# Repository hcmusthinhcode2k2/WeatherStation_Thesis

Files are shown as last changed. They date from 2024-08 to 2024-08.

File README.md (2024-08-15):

## Thesis Topic: "Design a weather monitoring station using NB-IoT technology"

### Description
The weather station model was designed over a 5-month period (March 2024 - August 2024), incorporating components such as PCB, sensors, and mechanical structure. The objective of this project is to develop a station capable of collecting weather data from various sensors and transmitting it to the ThingsBoard server. This enables visualization of the collected data, facilitating effective weather monitoring.

The project benefited from equipment and guidance provided by RPC, the company where I interned from October 2023 to December 2023.

### Technology
- **Hardware**: Designed using the open-source software KiCad 8.0.
- **Firmware**: Developed for the PIC32MM0256GPM048 microcontroller, leveraging existing RPC libraries such as Telit, Bootloader, and VCP_debug. Tools used include MPLAB X IDE version 6.20 and Serial Port Terminal version 1.5.0.4.
- **Server**: ThingsBoard is utilized to create a website with widgets for visualizing weather data, GPS-based map locations, warning clocks, and more.

### Model Images and Implementation Results
#### Weather Station Board
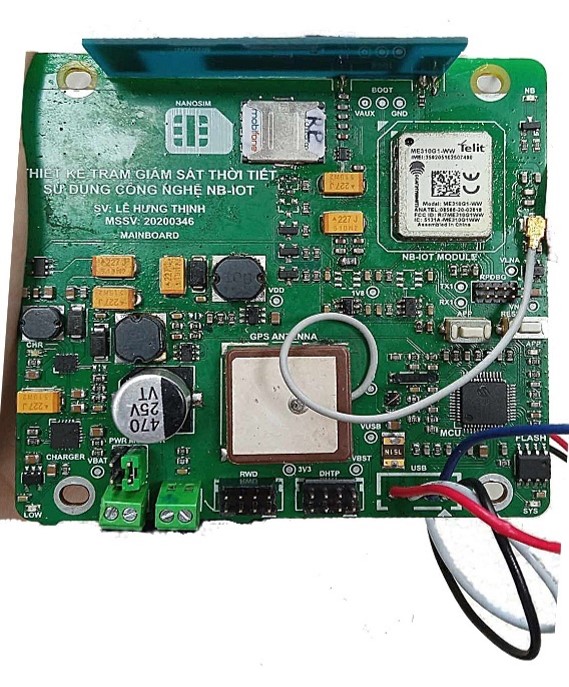
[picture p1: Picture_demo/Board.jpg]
Weather Station Board


#### Device Images
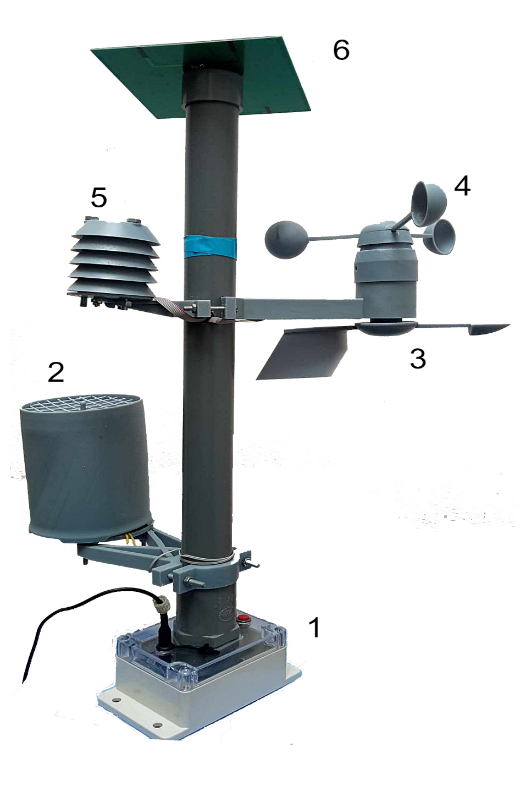
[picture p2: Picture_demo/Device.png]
Device Images


#### ThingsBoard Dashboard
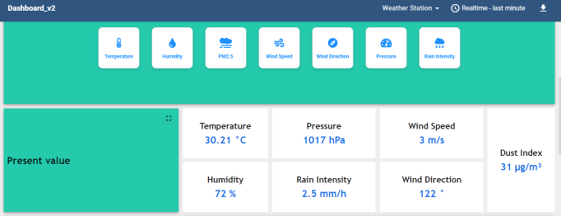
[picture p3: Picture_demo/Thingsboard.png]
ThingsBoard Dashboard

- [Access the ThingsBoard Dashboard](https://demo.thingsboard.io/dashboard/4821b720-32a0-11ef-9229-f3aa570680fb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)

### Developed After Defending The Thesis
Post-thesis, I built a web application using Next.js, integrating it with the ThingsBoard API for interactive weather data visualization. Supabase is used for backend services, including authentication via GitHub, data management, and real-time updates. The development process was influenced by insights from this [YouTube video](https://www.youtube.com/watch?v=zOgFMPC12Ag).
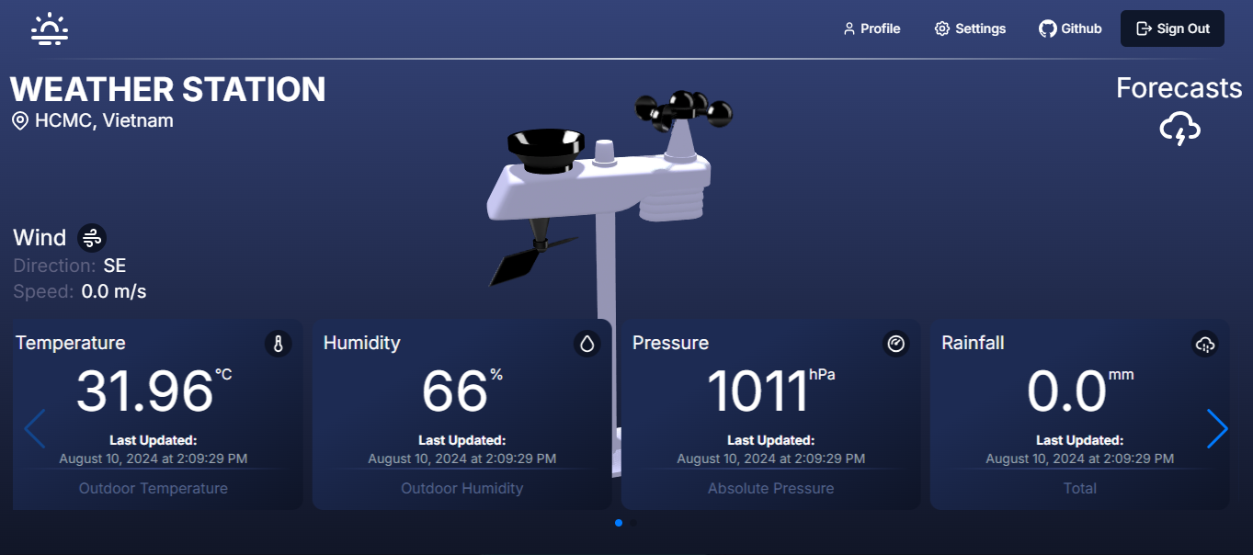
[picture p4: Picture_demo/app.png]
Web

- [Access the Web](https://iot-dashboard-2r98-git-master-hcmusthinhcode2k2s-projects.vercel.app/auth)
- **Test Credentials**: 
  - **Username**: test1@gmail.com
  - **Password**: Test123@
### Demo
[Demo1](https://www.youtube.com/watch?v=N3w6X92QKFQ)
[Demo2](https://youtu.be/iBSUhQx9wfY)

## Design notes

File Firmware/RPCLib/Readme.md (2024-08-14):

# RPC STATIC LIBRARY FOR MICROCHIP MCUs

Support MPALB XC Compilers

## 1. 8-Bit PIC MCUs

## 2. 8-Bit AVR MCUs

## 3. 16-Bit PIC MCUs

## 4. 32-Bit MIPS MCUs

## 5. 32-Bit ARM MCUs

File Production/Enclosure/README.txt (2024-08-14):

YAWS, Yet Another Weather Station by BennyI3 on Thingiverse: https://www.thingiverse.com/thing:6439737

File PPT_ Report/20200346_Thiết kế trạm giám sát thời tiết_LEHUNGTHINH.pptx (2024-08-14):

## KHOÁ LUẬN TỐT NGHIỆP CỬ NHÂN

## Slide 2

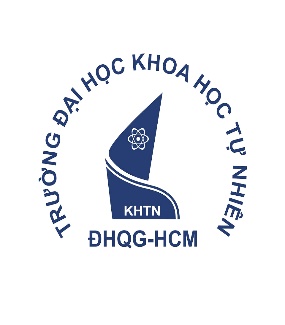
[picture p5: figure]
Không có mô tả ảnh.
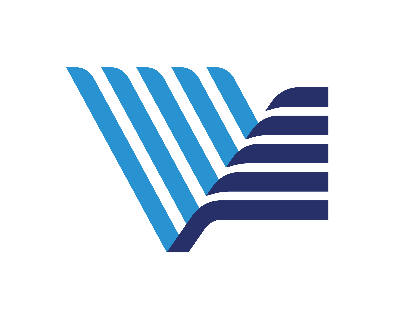
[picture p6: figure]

TRƯỜNG ĐẠI HỌC KHOA HỌC TỰ NHIÊN- ĐHQG THÀNH PHỐ HỒ CHÍ MINH
KHOA ĐIỆN TỬ - VIỄN THÔNG
BỘ MÔN MÁY TÍNH - HỆ THỐNG NHÚNG

Thành phố Hồ Chí Minh, Ngày 3 tháng 8 năm 2024

Đề tài:

THIẾT KẾ TRẠM GIÁM SÁT THỜI TIẾT
SỬ DỤNG CÔNG NGHỆ NB-IOT

Sinh viên : Lê Hưng Thịnh
MSSV : 20200346 – ĐTVT K20
GVHD : ThS. Nguyễn Quốc Khoa

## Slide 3

NỘI DUNG TRÌNH BÀY

1

TỔNG QUAN ĐỀ TÀI

2

THIẾT KẾ MÔ HÌNH

3

KIỂM THỬ – ĐÁNH GIÁ

KẾT LUẬN – HƯỚNG PHÁT TRIỂN

4

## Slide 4

1

TỔNG QUAN ĐỀ TÀI

1.1 Đặt vấn đề

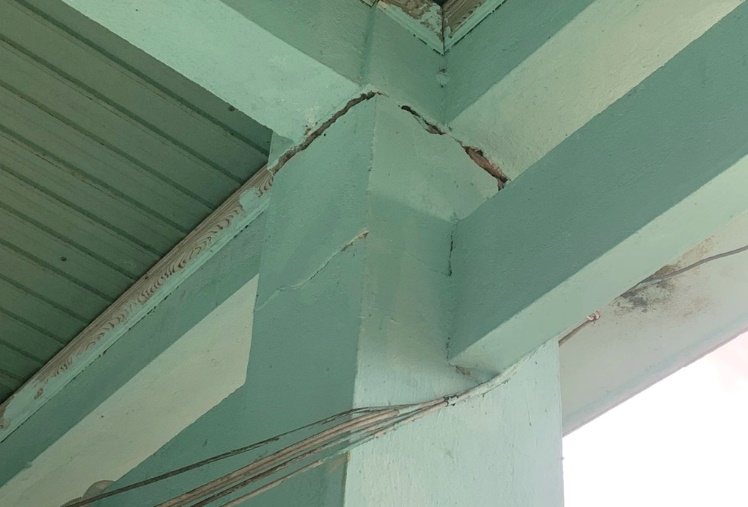
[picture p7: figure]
Động đất 5.0 độ ở Kon Tum: Nhiều công trình ở vùng tâm chấn bị nứt | Báo Dân trí

Động đất liên tiếp ở Kon Tum

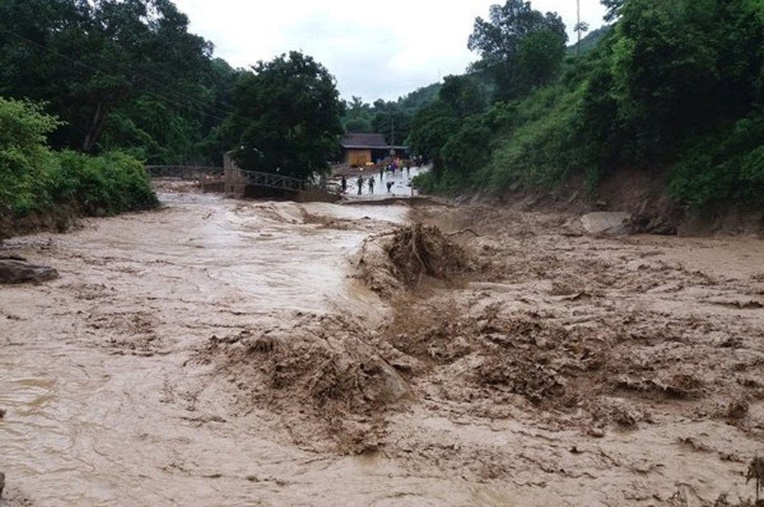
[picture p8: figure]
Vì sao miền Bắc xuất hiện nhiều điểm mưa lũ lịch sử trong tháng 7?

Lũ lớn ở miền bắc

Vấn đề : Giám sát dữ liệu thời tiết.
Trực quan hoá dữ liệu đưa ra cảnh báo kịp thời.

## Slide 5

1

TỔNG QUAN ĐỀ TÀI

Trạm giám sát thời tiết Wireless Vantage Pro2

1.1 Đặt vấn đề

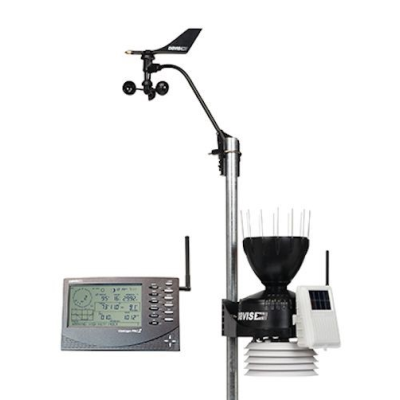
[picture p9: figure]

Ưu: Độ chính xác cao, thiết kế bền bỉ, khả năng mở rộng.
Nhược: Chi phí cao, truyền dữ liệu phạm vi ngắn, tiêu thụ năng lượng cao.

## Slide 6

1

TỔNG QUAN ĐỀ TÀI

1.2 Mục tiêu của khoá luận tốt nghiệp

Thiết kế một mô hình trạm giám sát thời tiết sử dụng công nghệ NarrowBand – Internet of Things (NB-IoT) có khả năng thu thập và gửi dữ liệu thời tiết lên server nhanh chóng:
- Dữ liệu từ cảm biến.
- Kết nối server bằng cách sử dụng mạng NB-IoT.
Giai đoạn của đề tài: giai đoạn sơ khai (tính toán thiết kế board mạch trên phần mềm Kicad, hàn lắp gia công, thiết kế chương trình, lắp đặt mô hình).

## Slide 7

2

THIẾT KẾ MÔ HÌNH

2.1 Yêu cầu chung của mô hình

- Thiết kế board mạch có đầy đủ các thành phần như nguồn, vi điều khiển, module truyền thông, …
- Có khả năng thu thập dữ liệu thời tiết với mức độ chính xác tương đối.
- Thực hiện kết nối server bằng mạng NarrowBand – Internet of Things (NB-IoT).
- Trực quan hoá và cảnh báo dựa trên dữ liệu thời tiết nhận được trên server server thông qua Thingsboard,.
- Lắp rắp thiết kế được mô hình hoàn chỉnh.

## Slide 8

2

THIẾT KẾ MÔ HÌNH

2.1 Tổng quan mô hình

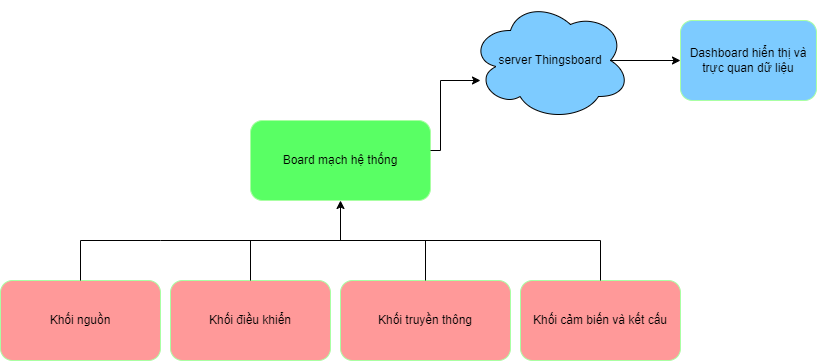
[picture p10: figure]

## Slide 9

2

THIẾT KẾ MÔ HÌNH

2.2 Phân hệ thiết kế phần cứng

Khối nguồn

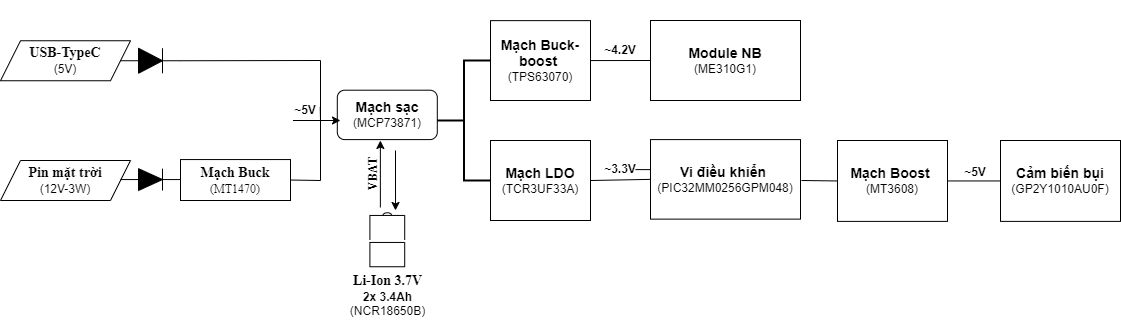
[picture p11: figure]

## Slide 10

2

THIẾT KẾ MÔ HÌNH

2.2 Phân hệ thiết kế phần cứng

Khối điều khiển

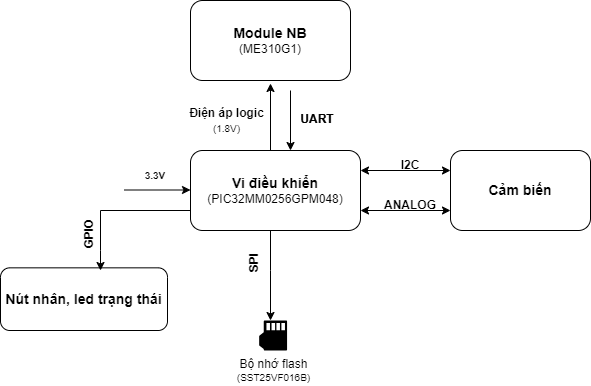
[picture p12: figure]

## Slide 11

2

THIẾT KẾ MÔ HÌNH

2.2 Phân hệ thiết kế phần cứng

Khối truyền thông

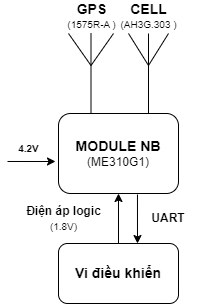
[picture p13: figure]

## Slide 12

2

THIẾT KẾ MÔ HÌNH

2.2 Phân hệ thiết kế phần cứng

Khối cảm biến và kết cấu

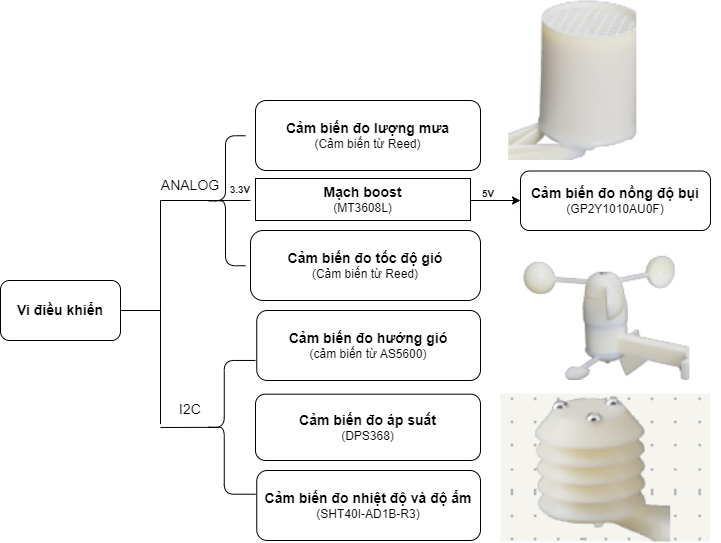
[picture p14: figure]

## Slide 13

2

THIẾT KẾ MÔ HÌNH

2.3 Phân hệ thiết kế chương trình

Cấu trúc chương trình điều khiển

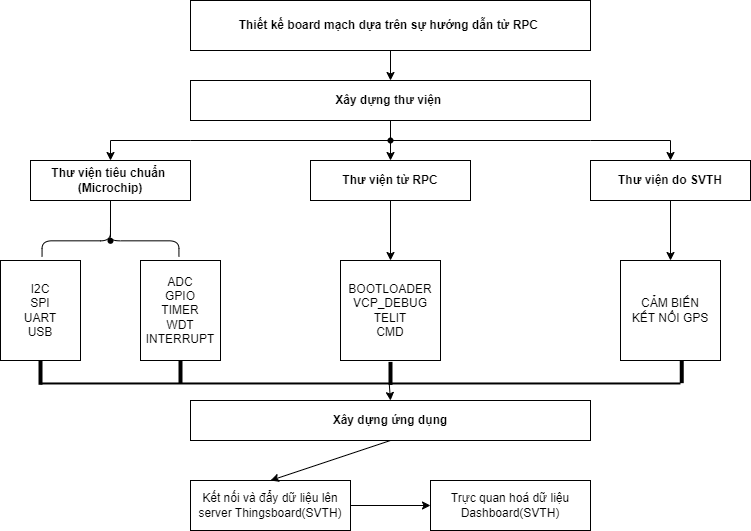
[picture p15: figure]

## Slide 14

2

THIẾT KẾ MÔ HÌNH

2.3 Phân hệ thiết kế chương trình

Lưu đồ Module NB hoạt động.

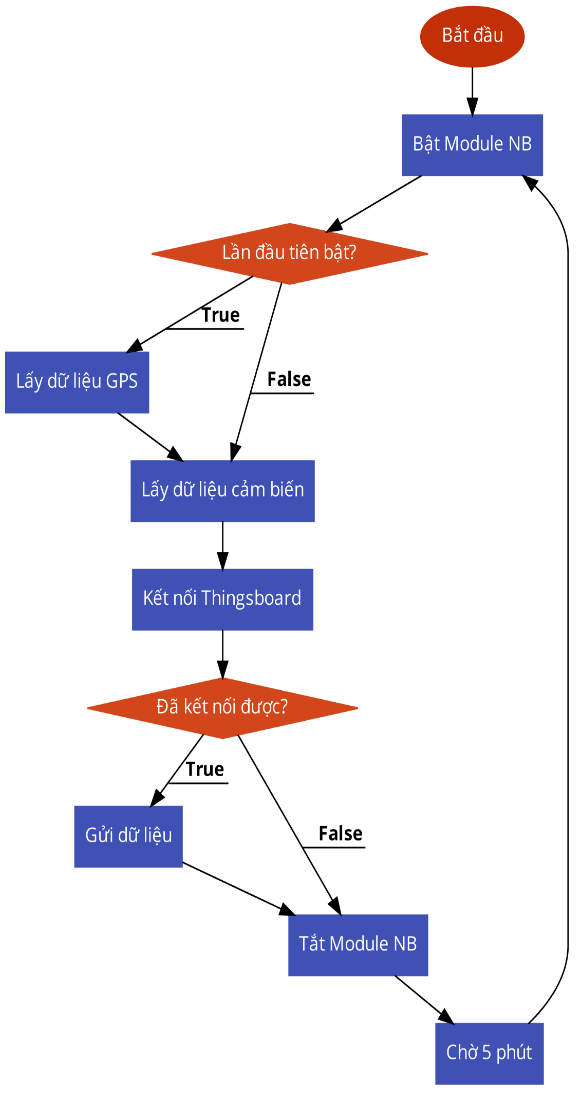
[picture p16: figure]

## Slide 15

2

THIẾT KẾ MÔ HÌNH

2.3 Phân hệ thiết kế chương trình

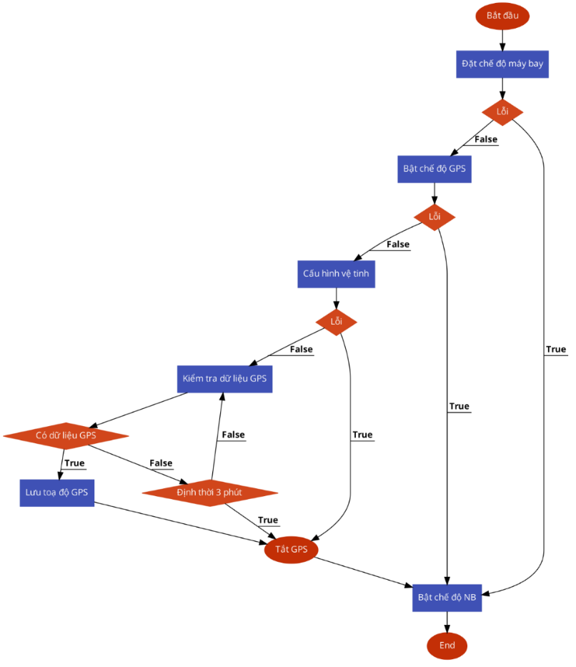
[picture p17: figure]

Lưu đồ thuật toán lấy dữ liệu GPS.

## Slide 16

2

THIẾT KẾ MÔ HÌNH

2.4 Phân hệ thiết kế chương trình

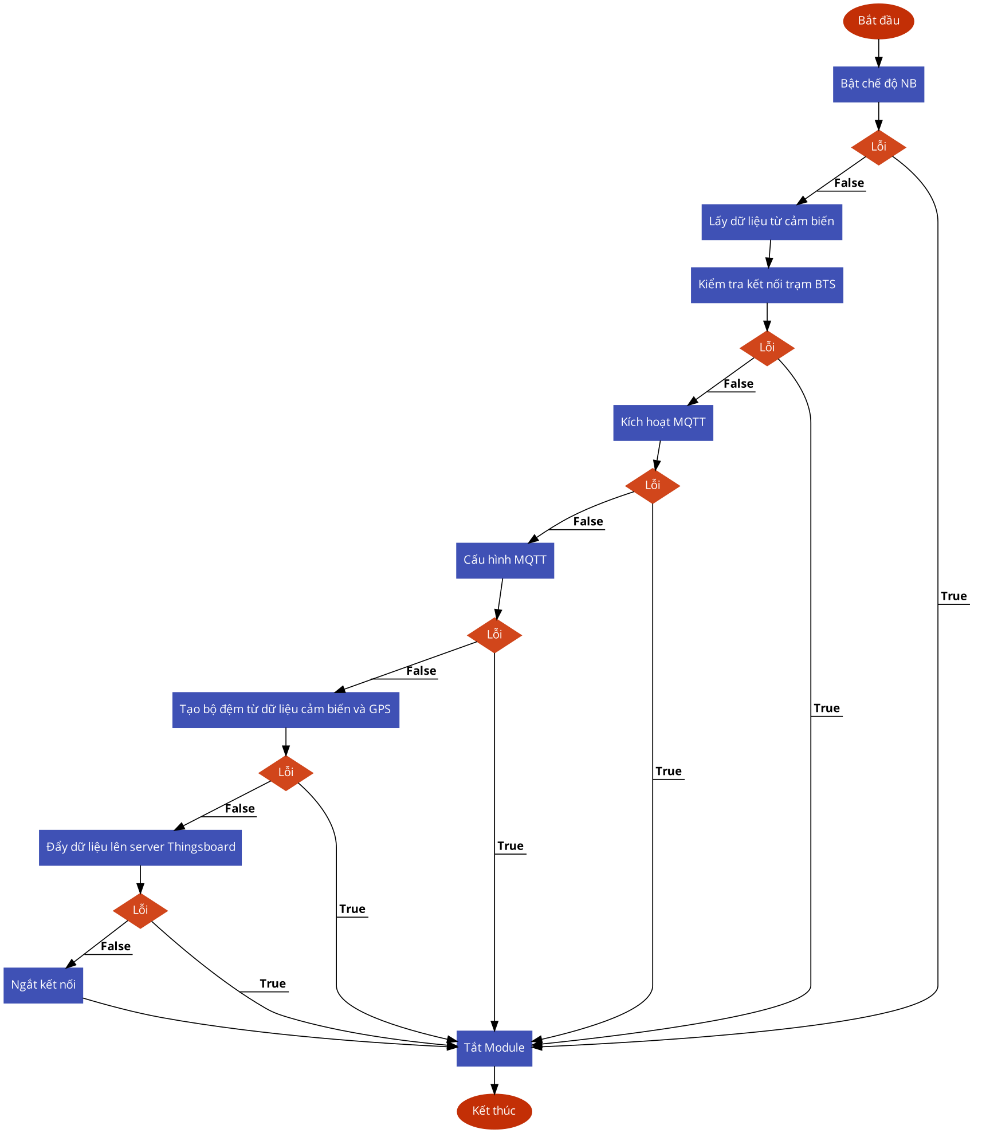
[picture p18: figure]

Lưu đồ thuật toán lấy dữ liệu và gửi
dữ liệu lên server.

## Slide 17

2

THIẾT KẾ MÔ HÌNH

2.4 Phân hệ thiết kế Dashboard trên Thingsboard

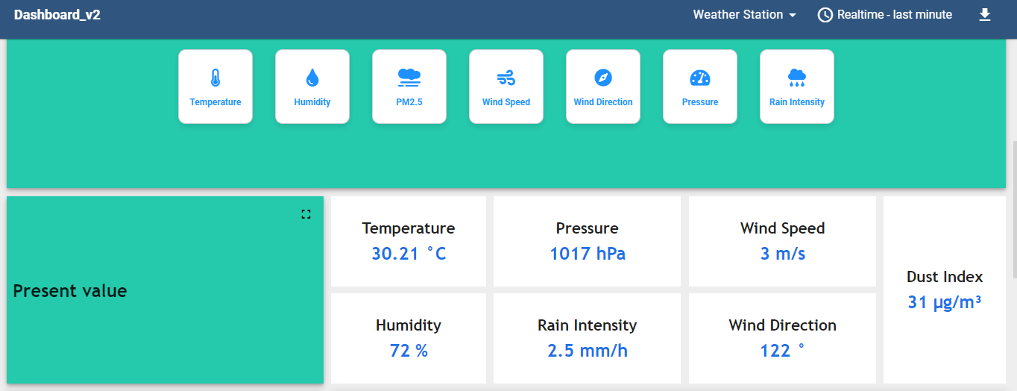
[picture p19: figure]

Thiết kế trang tổng quan

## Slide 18

2

THIẾT KẾ MÔ HÌNH

2.4 Phân hệ thiết kế Dashboard trên Thingsboard

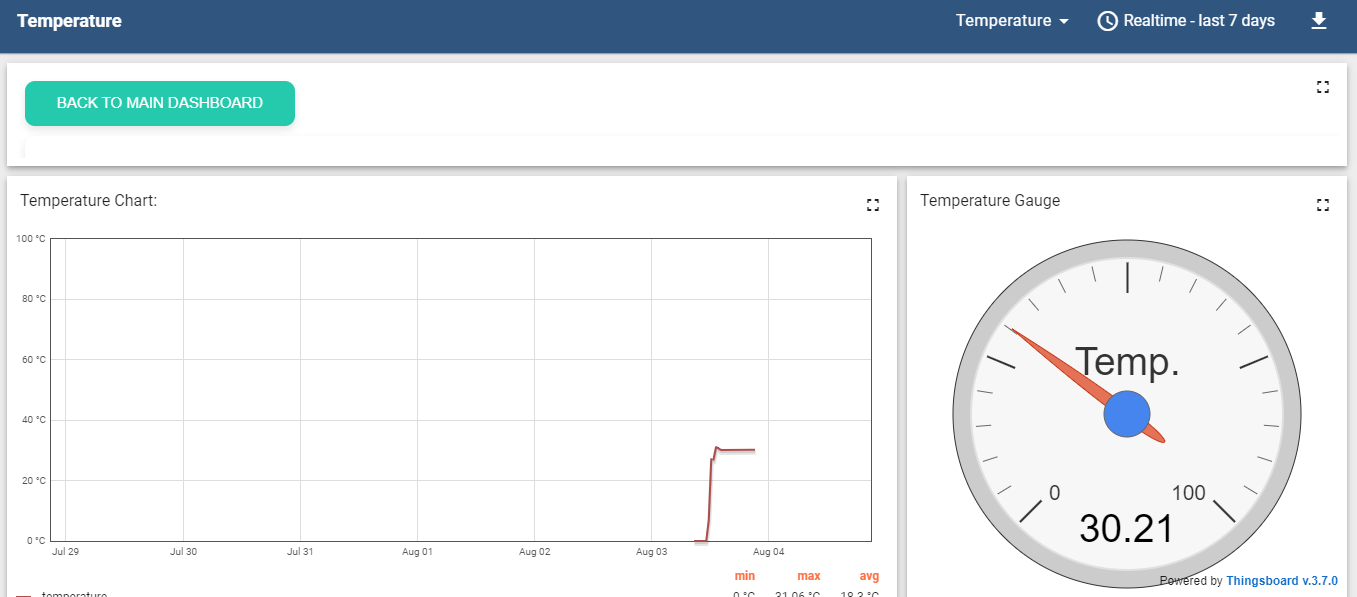
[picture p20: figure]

Thiết kế trang con

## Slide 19

3

KIỂM THỬ - ĐÁNH GIÁ

3.1 Điều kiện kiểm thử (ĐKKT)

Thời gian: Sau khi hàn lắp gia công board mạch.
Hệ thống : Nguồn tại các vị trí như chân vi điều khiển, chân module NB, chân nguồn vào pin Li-Ion, pin mặt trời, nguồn tại các chân IC Buck, boost.
Phương tiện: Đồng hồ VOM.

Board mạch hệ thống

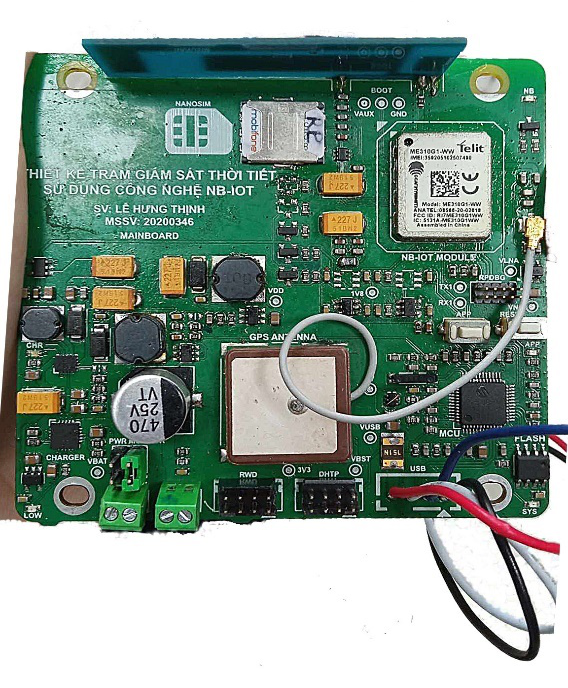
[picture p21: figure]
Bản xem trước hình ảnh

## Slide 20

3

KIỂM THỬ - ĐÁNH GIÁ

3.2 Kiểm tra mô hình hoạt động

Thời gian: Sau khi lắp ráp mô hình hoàn chỉnh.
Hệ thống : Chương trình điều khiển hoạt động thu thập dữ liệu của cảm biến, kết nối GPS và truyền dữ liệu lên server.
Phương tiện:Bootloader, VCP_DEBUG.

Mô hình đã lắp đặt hoàn chỉnh


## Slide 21

3

KIỂM THỬ - ĐÁNH GIÁ

3.2 Kiểm tra dữ liệu trên server

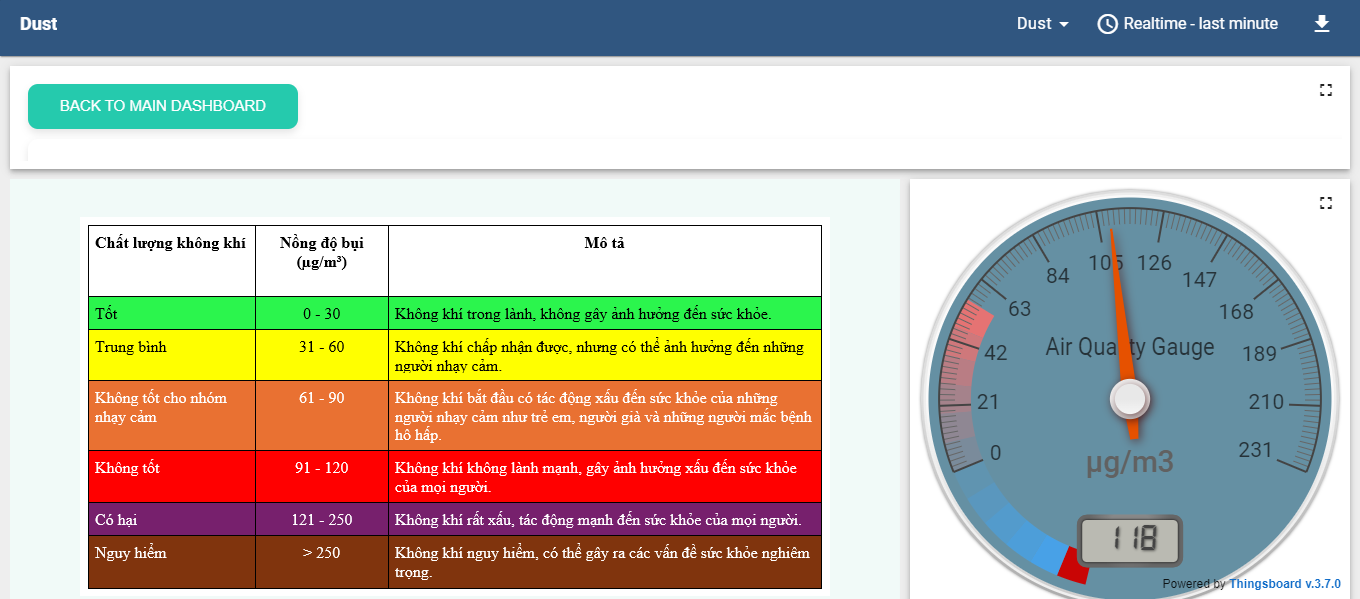
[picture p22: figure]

Thời gian: Sau khi chương trình kích hoạt
Hệ thống : Đã kết nối đến server
Phương tiện: Thingsboard (bản demo).

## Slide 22

3

KIỂM THỬ - ĐÁNH GIÁ

3.3 Đánh giá

Kết quả thực nghiệm:
Đối với board mạch:
- Nguồn tương đối chính xác cho vi điều khiển (~3.25V), Pin Li-Ion (~4.1V), module NB (~3.67V), cảm biến bụi (~5.1V). Pin năng lượng mặt trời (~11.5V).
Đối với mô hình hoàn chỉnh:
- Thu thập được các giá trị thời tiết từ cảm biến, GPS tương đối chính xác.
- Kết nối và truyền dữ liệu lên server tại một số địa điểm như CS1 ĐHKHTN, phường 12 quận Tân Bình, ktx khu B - ĐHQGHCM.
- Tiêu thụ năng lượng thấp theo tính toán khoảng 7 ngày.

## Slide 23

4

KẾT LUẬN – HƯỚNG PHÁT TRIỂN

4.1 Kết luận

Đạt được

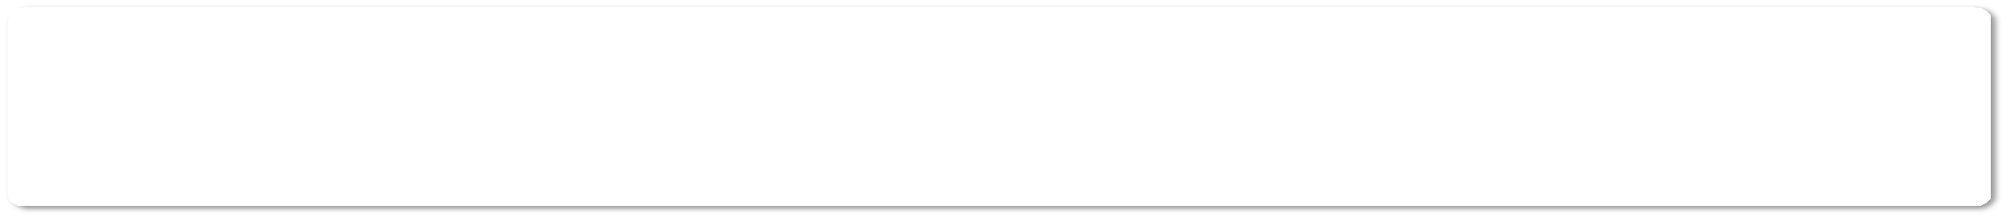
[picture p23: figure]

Khoá luận đã thiết kế thành công một mô hình IoT.
- Mô hình thực hiện đươc những tính năng đề ra.
- Mô hình có kết cấu và đi dây gọn gàn, dễ di chuyển.

- Trạm dừng lại ở mô hình với kết cấu được in3D nhựa resin.
- Độ chính xác cảm biến chưa tốt vì mẫu in 3D bị mốp méo, GPS sai lệch 5-20 m.
- Giao diện Dashboard trên Thingsboard chưa thiết kế tối ưu cho người dùng điện thoại xem.
- Chưa thực nghiệm được ở nhiều ĐKKT khác nhau.

Hạn chế

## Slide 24

4

KẾT LUẬN – HƯỚNG PHÁT TRIỂN

4.2 Hướng phát triển

- Tối ưu năng lượng tăng tuổi thọ của pin Li-Ion.
- Xây dựng thêm nhiều trạm có kết cấu vững chắc hơn. Từ đó có nhiều dữ liệu thời tiết, xây dựng mô hình dư báo thời tiết.
- Kiểm tra đánh giá chất lượng mạng NB-IoT tại nhiều nơi trước khi lắp đặt thử nghiệm trạm.
- Xây dựng thêm các nền tảng app/web với server cá nhân từ đó cải thiện khả năng bảo mật cũng như thiết kế giao diện người dùng thân thiệt trên IOS, Android.

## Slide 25

CẢM ƠN SỰ THEO DÕI CỦA QUÝ THẦY CÔ.

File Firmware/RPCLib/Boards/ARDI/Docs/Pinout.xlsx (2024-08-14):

Pin | Port | Name | Type | Init State | Note
21 | RA0 | UNO_VREF | Analog Input | x
22 | RA1 | UNO_AN3 | Analog Input | x
13 | RA10 | BUTTON | Digital Input | x
8 | RA15 | LED2 | Digital Output | 0
32 | RA2 | OSC1 | XTAL | x | XTAL 12MHz
33 | RA3 | OSC2 | XTAL | x | XTAL 12MHz
36 | RA4 | UNO_TXD | UART 3 TX | 1
20 | RA6 | LIGHT_INT | Digital Input | x
14 | RA7 | LED1 | Digital Output | 0
34 | RA8 | ACC_INT1 | Digital Input | x
37 | RA9 | UNO_MISO | SPI2 SDI | x
23 | RB0 | ICSP_PGD | Digital Input | x
24 | RB1 | ICSP_PGC | Digital Input | x
9 | RB10 | USB_N | USB D- | x
10 | RB11 | USB_P | USB D+ | x
12 | RB13 | VBAT_DIV | Analog Input | x | Rt/Rb=825k/825k
15 | RB14 | CELL_RING | Digital Input, Pullup | x | Active low, connect to Cellular pin C125/RING
16 | RB15 | TEM_INT | Digital Input | x
25 | RB2 | UNO_SDA | I2C2 SDA | x
26 | RB3 | UNO_SCL | I2C2 SCL | x
35 | RB4 | UNO_RXD | UART 3 RX | x
45 | RB5 | UNO_MOSI | SPI2 SDO | x
46 | RB6 | USB_VBUS | USB VBUS | x
47 | RB7 | UNO_SCLK | SPI2 SCK | x
48 | RB8 | SENSOR_SCL | I2C1 SCL | x
1 | RB9 | SENSOR_SDA | I2C1 SDA | x
27 | RC0 | UNO_AN1 | Analog Input | x
28 | RC1 | UNO_AN2 | Analog Input | x
44 | RC12 | CELL_PWR_EN | Digital Output | 0 | On/Off power of Cellular module
29 | RC2 | ACC_INT2 | Digital Input | x
39 | RC3 | UNO_INT1 | Digital Input | x
40 | RC4 | UNO_IO3 | Digital Input | x
41 | RC5 | UNO_INT0 | Digital Input | x
2 | RC6 | CELL_RXD | UART 2 RX | x | Connect to Cellular pin C104/RXD
3 | RC7 | CELL_TXD | UART 2 TX | 1 | Connect to Cellular pin C103/TXD
4 | RC8 | CELL_HWSDN | Digital Output | 0 | Active high, connect to Cellular HW_SHUTDOWN
5 | RC9 | CELL_WDT | Digital Input, Pullup | x | Active low, connect to Cellular GPIO_10
38 | RD0 | FLASH_CS_N | Digital Output | 1

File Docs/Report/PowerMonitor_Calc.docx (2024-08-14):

V_(REF) =3300 mV ADC_(RES) =4096

R_t =53.6K

R_b =10.0K

ADC_(RES) =4096

V_(SEN) =ADC_(VAL) ×(V_(REF))/(ADC_(RES))

V_o =(V_(SEN))/(R_b)×(R_t +R_b )=ADC_(VAL) ×(V_(REF))/(ADC_(RES))×(R_t +R_b)/(R_b)=ADC_(VAL) ×3300/4096×(R_t +R_b)/(R_b)

R_t =R_11 =53.6K;R_b =R_12 =10.0K

V_(5V) =ADC_(VAL) ×3300/4096×(53.6K+10.0K)/(10.0K)=ADC_(VAL) ×5247/1024

R_t =R_8 =43.0K;R_b =R_9 =12.0K

V_(NB) =ADC_(VAL) ×3300/4096×(43.0K+12.0K)/(12.0K)=ADC_(VAL) ×15125/4096

R_t =R_2 =5.1K;R_b =R_3 =10.0K

V_(SOLAR) =ADC_(VAL) ×3300/4096×(5.1K+10.0K)/(10.0K)=ADC_(VAL) ×4983/4096

R_t =R_19 =680.0K;R_b =R_20 =10.0K

V_(BAT) =ADC_(VAL) ×3300/4096×(680.0K+10.0K)/(10.0K)=ADC_(VAL) ×56925/1024

V_(NBAUX) =ADC_(VAL) ×3300/4096=ADC_(VAL) ×825/1024

V_(BG) =ADC_(VAL) ×3300/4096=ADC_(VAL) ×825/1024

V_(CORE) =ADC_(VAL) ×3300/4096=ADC_(VAL) ×825/1024

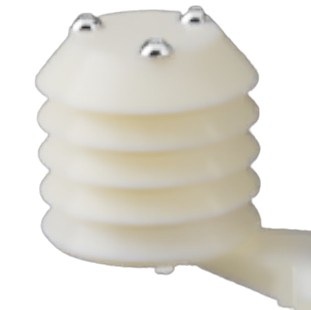
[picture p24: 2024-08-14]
Docs/Images/HumiditySensor.png

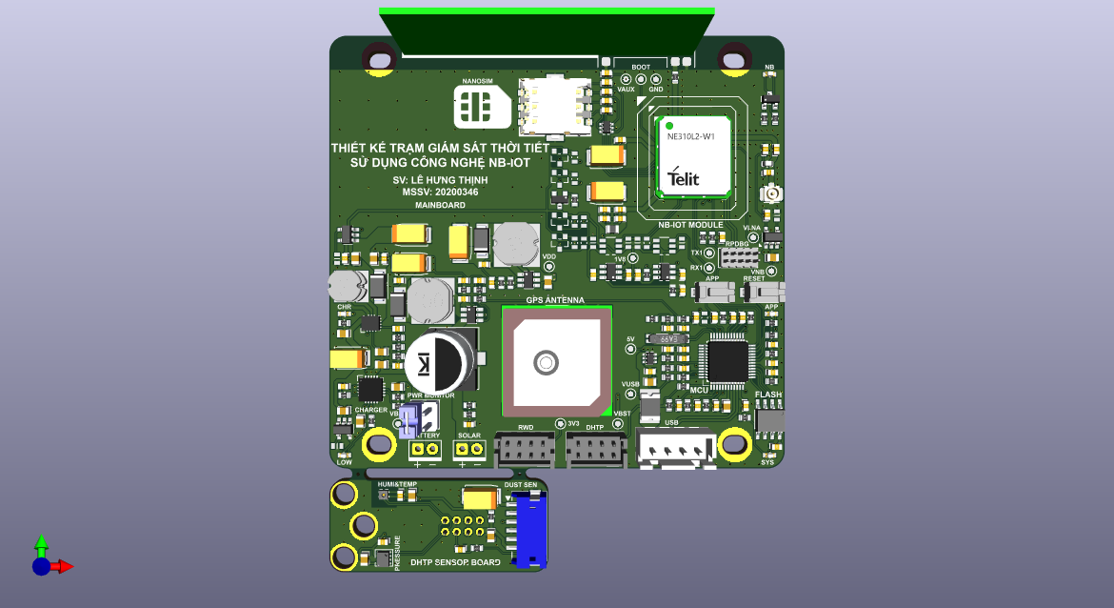
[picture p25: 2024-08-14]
Production/Main-Sen/Pictures/Top.png

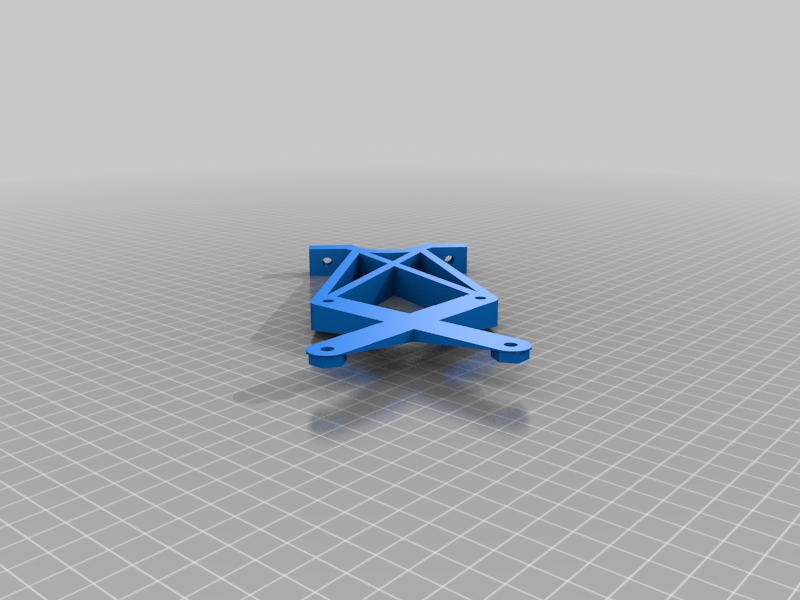
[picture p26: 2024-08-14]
Docs/Images/a5ba8f14-daac-4e57-8c12-72183b6821ad.png

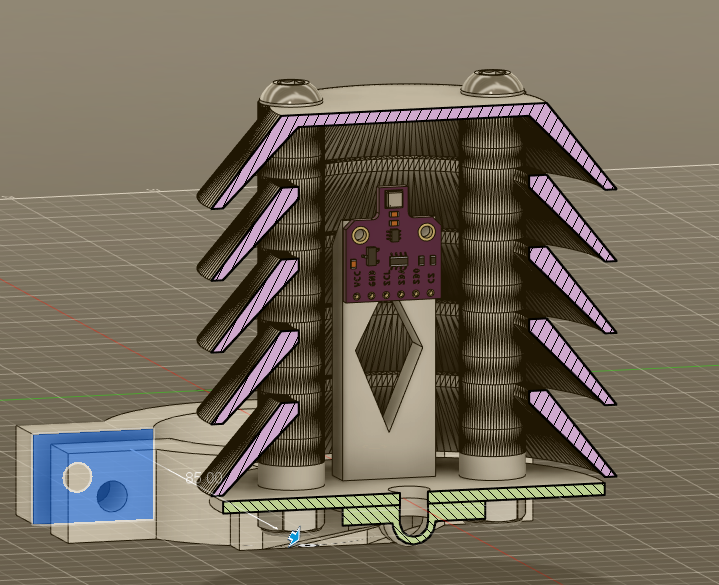
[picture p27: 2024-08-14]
Docs/Images/4b5391d4-0b75-4b54-ad87-2e042f95fe6b.png

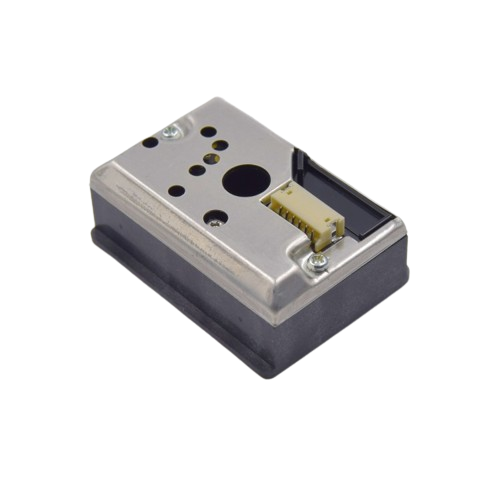
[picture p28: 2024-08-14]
Docs/Images/1-750x750-removebg-preview.png

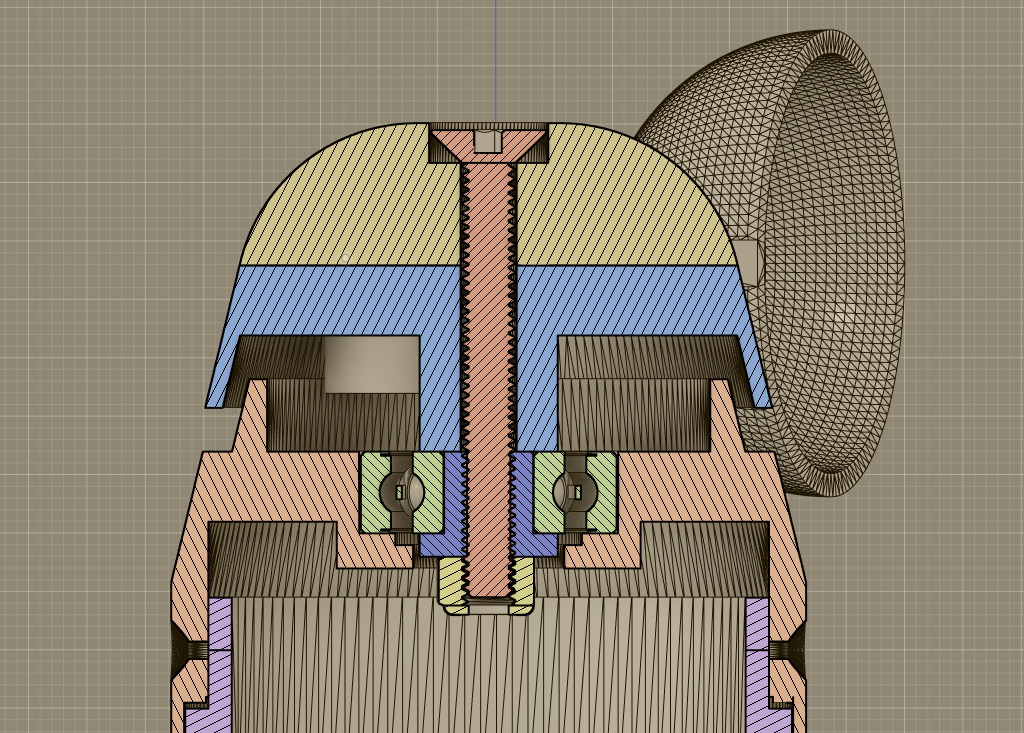
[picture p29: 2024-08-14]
Docs/Images/2bd4bd71-de33-4c61-b7e4-2078deda2e9a.png

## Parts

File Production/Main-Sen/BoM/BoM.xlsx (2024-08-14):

# | MNP | MFT | Description | Reference | Qty | Price | Sub-Price | Stock Link | Note
14 | VEC2R7106QC | VinaTech | SUPERCAP EDLC 10F 2.7V ESR 55mR | C57,C58 | 2 | 1.1285 | 2.2570 | https://banlinhkien.com/sieu-tu-10f-2.7v-10x30mm-vec2r7106qc-p12117721.html
38 | AS5600-I2C | OEM | 12-BIT MAGNETIC ROTARY | MD4 | 1 | 2.2000 | 2.2000 | https://icdayroi.com/module-cam-bien-goc-quay-bang-tu-truong-as5600-i2c
64 | DPS368XTSA1 | Infineon | SENSOR 17.4PSIG 24BIT 8VLGA | U14 | 1 | 3.1800 | 3.1800 | https://www.digikey.com/en/products/detail/infineon-technologies/DPS368XTSA1/10244079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
55 | MCP73871T-2CCI/ML | Microchip | IC BATT CHG LI-ION 1CELL 4.2V 20QFN | U4 | 1 | 2.4100 | 2.4100 | https://www.digikey.com/en/products/detail/microchip-technology/MCP73871T-2CCI-ML/1680976
~~58~~ | ~~PIC32MM0256GPM048-I/PT~~ | ~~Microchip~~ | ~~IC MCU 32BIT 256KB FLASH 48TQFP~~ | ~~U7~~ | ~~1~~ | ~~0~~ | ~~0~~ | https://www.digikey.com/en/products/detail/microchip-technology/PIC32MM0256GPM048-I-PT/7354721
~~57~~ | ~~SST25VF016B-50-4C-S2AF~~ | ~~Microchip~~ | ~~IC FLASH 16MBIT SPI 50MHZ 8SOIC~~ | ~~U6~~ | ~~1~~ | ~~0~~ | ~~0~~ | https://www.digikey.com/en/products/detail/microchip-technology/SST25VF016B-50-4C-S2AF/2297794
62 | SHT40I-AD1B-R3 | Sensirion | INDUSTRIAL SENSOR HUMID/TEMP | U12 | 1 | 2.1000 | 2.1000 | https://www.digikey.com/en/products/detail/sensirion-ag/SHT40I-AD1B-R3/15792545
~~51~~ | ~~MK20/2-B-100W~~ | ~~Standex~~ | ~~SENSOR REED SW SPST-NO CBL LEADS~~ | ~~SW1,SW2~~ | ~~2~~ | ~~0~~ | ~~0~~ | https://www.digikey.com/en/products/detail/standex-meder-electronics/MK20-2-B-100W/3131691
~~35~~ | ~~ME310G1WW05T060400~~ | ~~Telit~~ | ~~RF TXRX MODULE AT&T/VZW~~ | ~~MD1~~ | ~~1~~ | ~~0~~ | ~~0~~ | https://www.digikey.com/en/products/detail/telit-cinterion/ME310G1WW05T060400/20484831
54 | LM66100DCKR | TI | IC OR CTRLR IDEAL DIODE SC70-6 | U3 | 1 | 0.4100 | 0.4100 | https://www.digikey.com/en/products/detail/texas-instruments/LM66100DCKR/10273183
53 | TPS630701RNMR | TI | IC REG BCK BST 5V 2A 15VQFN | U2 | 1 | 1.8900 | 1.8900 | https://www.digikey.com/en/products/detail/texas-instruments/TPS630701RNMR/6175215
41 | RC0603FR-075K1L | YAGEO | RES SMD 5.1K OHM 1% 1/10W 0603 | R2,R5,R23,R24 | 4 | 0.0020 | 0.0080 | https://www.digikey.com/en/products/detail/yageo/RC0603FR-075K1L/727268
44 | RT0603FRE0736KL | YAGEO | RES SMD 36K OHM 1% 1/10W 0603 | R8 | 1 | 0.0020 | 0.0020 | https://www.digikey.com/en/products/detail/yageo/RT0603FRE0736KL/1075328
36 | 1575R-A | AntennaHome | GPS ACTIVE ANT 19X19 IPEX CONNECTOR RF CABLE 10CM | MD2 | 1 | 1.0530 | 1.0530 | https://www.thegioiic.com/1575r-a-ang-ten-active-gps-19x19-dau-ipex-cap-rf-10cm
~~1~~ | ~~AH3G.303~~ | ~~AntennaHome~~ | ~~ANTENNA SMD 2G/3G/4G 690~2700MHz~~ | ~~ANT1~~ | ~~1~~ | ~~0~~ | ~~0~~ | https://www.thegioiic.com/ah3g-303-ang-ten-smd-2g-3g-4g-690-2700mhz
25 | BK2125HS101-T | Taiyo Yuden | FERRITE BEAD 100 OHM 0805 1LN | FT1 | 1 | 0.0180 | 0.0180 | https://www.thegioiic.com/bk2125hs101-t-ferrite-beads-100-ohm-0805
31 | DF11-8DP-2DSA(08) | Hirose | CONN HEADER VERT 8POS 2MM | J6,J7,J8 | 3 | 0.0790 | 0.2370 | https://www.thegioiic.com/cong-dc3-8-chan-2-hang-2-0mm-chan-thang
2 | U.FL-R-SMT-1(40) | Hirose | CONN U.FL RCPT STR 50 OHM SMD | ANT2 | 1 | 0.0700 | 0.0700 | https://www.thegioiic.com/cong-rf-1th-ipex-u-fl-r-smt-2-chan-dan-smd
32 | SDE0604A-2R2M | Bourns | FIXED IND 2.2UH 4.35A 31MOHM SMD 5852 | L1 | 1 | 0.0440 | 0.0440 | https://www.thegioiic.com/cuon-cam-dan-smd-cd53-5852-2r2-2-2uh-3-5a
33 | SDE0805A-100M | Bourns | FIXED IND 10UH 3.2A 70 MOHM SMD | L2,L4 | 2 | 0.0440 | 0.0880 | https://www.thegioiic.com/cuon-cam-dan-smd-cd75-7855-100-10uh-2-3a
26 | XH2.54-4P-R | OEM | PIN HEADER R/A 1x4POS 2.54MM | J1 | 1 | 0.0130 | 0.0130 | https://www.thegioiic.com/dau-xh-2-54mm-4-chan-cong-xuyen-lo
61 | S6B-ZR-SM4A-TF | JST | CONN HEADER SMD R/A 6POS 1.5MM | U11 | 1 | 0.0350 | 0.0350 | https://www.thegioiic.com/dau-zh-1-5mm-6-chan-dan-smd-nam-ngang
15 | ZH1.5-10CM | OEM | ZH1.5 Bus Wire Female-Female Connector 6 Way, Pitch 1.5mm, Length 10cm | CB1 | 1 | 0.1540 | 0.1540 | https://www.thegioiic.com/day-bus-zh1-5-cai-cai-6-tiep-diem-1-5mm-dai-10cm
16 | IDC8x2-30CM | OEM | IDC Cable Female-Female Same Direction 8-Way Connector, Pitch 2.0mm, Length 30cm | CB2 | 1 | 1.0090 | 1.0090 | https://www.thegioiic.com/day-cap-idc-cai-cai-cung-huong-8-tiep-diem-2-0mm-dai-30cm
17 | IDC8x2-50CM | OEM | IDC Cable Female-Female Same Direction 8-Way Connector, Pitch 2.0mm, Length 50cm | CB3 | 1 | 1.2280 | 1.2280 | https://www.thegioiic.com/day-cap-idc-cai-cai-cung-huong-8-tiep-diem-2-0mm-dai-50cm
48 | RC0603JR-070RL | YAGEO | RES SMD 0 OHM JUMPER 1/10W 0603 | R21,R27,R29,Z1 | 4 | 0.0020 | 0.0080 | https://www.thegioiic.com/dien-tro-0-ohm-0603-1-
46 | RC0603FR-07100KL | YAGEO | RES SMD 100K OHM 1% 1/10W 0603 | R17 | 1 | 0.0020 | 0.0020 | https://www.thegioiic.com/dien-tro-100-kohm-0603-1-
42 | RC0603FR-0710KL | YAGEO | RES SMD 10K OHM 1% 1/10W 0603 | R3,R4,R9,R12,R16,R18,R20,R22,R25,R30,R35 | 11 | 0.0020 | 0.0220 | https://www.thegioiic.com/dien-tro-10-kohm-0603-1-
50 | RC0603FR-13150KL | YAGEO | RES SMD 150K OHM 1% 1/10W 0603 | R37,R38 | 2 | 0.0020 | 0.0040 | https://www.thegioiic.com/dien-tro-150-kohm-0603-1-
49 | RC0603JR-07150RL | YAGEO | RES SMD 150 OHM 5% 1/10W 0603 | R33 | 1 | 0.0014 | 0.0014 | https://www.thegioiic.com/dien-tro-150-ohm-0603-5-
40 | AC0603JR-071KL | YAGEO | RES SMD 1K OHM 5% 1/10W 0603 | R1,R6,R10,R13,R14,R15,R26,R28,R31,R32,R36 | 11 | 0.0014 | 0.0154 | https://www.thegioiic.com/dien-tro-1-kohm-0603-5-
45 | RC0603FR-0753K6L | YAGEO | RES SMD 53.6K OHM 1% 1/10W 0603 | R11 | 1 | 0.0020 | 0.0020 | https://www.thegioiic.com/dien-tro-53-6-kohm-0603-1-
47 | RC0603FR-07680KL | YAGEO | RES SMD 680K OHM 1% 1/10W 0603 | R19 | 1 | 0.0020 | 0.0020 | https://www.thegioiic.com/dien-tro-680-kohm-0603-1-
43 | AC0603FR-0775KL | YAGEO | RES SMD 75K OHM 1% 1/10W 0603 | R7,R34 | 2 | 0.0020 | 0.0040 | https://www.thegioiic.com/dien-tro-75-kohm-0603-1-
37 | GP2Y1014AU | SHARP | DUST SENSOR UNIT | MD3 | 1 | 4.0790 | 4.0790 | https://www.thegioiic.com/gp2y1014au-cam-bien-bui-pm2-5
29 | PR20B05VBDN | METZ | PIN HEADER, THR, DUAL ROW, 1.27 | J4 | 1 | 0.1970 | 0.1970 | https://www.thegioiic.com/hang-rao-duc-doi-1-27mm-80-chan-2-hang-cao-7-2mm-xuyen-lo
28 | PH2RA-04-UA | Adam Tech | CONN HEADER R/A 2x2POS 2.54MM | J3 | 1 | 0.1100 | 0.1100 | https://www.thegioiic.com/hang-rao-duc-doi-2-54mm-80-chan-cong-2-hang-xuyen-lo
34 | HBLS1608-47NJ | HYHONGYEX | FIXED IND 47NH 380MA 700MOHM SMD 0603 | L3 | 1 | 0.0180 | 0.0180 | https://www.thegioiic.com/hbls1608-47nj-cuon-cam-47nh-0603-380ma
21 | B1911UD--20D001014U1930 | Harvatek | LED ORANGE DIFFUSED 0603 SMD | D5 | 1 | 0.0150 | 0.0150 | https://www.thegioiic.com/led-cam-0603-dan-smd-trong-suot-harvatek
19 | B1931USD-20D000814U1930 | Harvatek | LED RED DIFFUSED 0603 SMD | D3 | 1 | 0.0150 | 0.0150 | https://www.thegioiic.com/led-do-0603-dan-smd-trong-suot-harvatek
23 | E1221NB--05D000814U1930 | Harvatek | LED BLUE DIFFUSED 0603 SMD | D7 | 1 | 0.0150 | 0.0150 | https://www.thegioiic.com/led-xanh-duong-0603-dan-smd-trong-suot-harvatek
20 | B1931NG--20D001114U1930 | Harvatek | LED GREEN DIFFUSED 0603 SMD | D4 | 1 | 0.0150 | 0.0150 | https://www.thegioiic.com/led-xanh-la-0603-dan-smd-trong-suot-harvatek
56 | MCP1700T-3302E/TT | Microchip | IC REG LINEAR 3.3V 250MA SOT23-3 | U5 | 1 | 0.1320 | 0.1320 | https://www.thegioiic.com/mcp1700t-3302e-tt-ic-on-ap-3-3v-250ma
24 | MF-MSMF075/24-2 | Bourns | PTC RESET FUSE 24V 750MA 1812 | F1 | 1 | 0.1540 | 0.1540 | https://www.thegioiic.com/mf-msmf075-24-2-cau-chi-tu-phuc-hoi-1812-24v-0-75a
52 | MT1470 | AEROSEMI | IC BUCK REG MULTI CONFIG ADJ SOT-23-6 | U1 | 1 | 0.0830 | 0.0830 | https://www.thegioiic.com/mt1470-ic-dieu-chinh-giam-ap-2a-sot-23-6
63 | MT3608L | AEROSEMI | IC BOOST REG MULTI CONFIG ADJ SOT-23-6 | U13 | 1 | 0.1320 | 0.1320 | https://www.thegioiic.com/mt3608-ic-dieu-chinh-tang-ap-2a-sot-23-6
30 | SIM8051-6-0-14-01-A | GCT | NANO SIM PUSH PULL, 6P, SMT, 1.3 | J5 | 1 | 0.1540 | 0.1540 | https://www.thegioiic.com/ns-ol-6p-khay-cam-nanosim-6-chan-open-lock
4 | EVQ-PE105K | Panasonic | SWITCH TACTILE SPST-NO 0.05A 12V | BT1 | 1 | 0.0220 | 0.0220 | https://www.thegioiic.com/nut-nhan-3x6mm-cao-5mm-2-chan-smd-dau-trang
5 | EVQ-PE105K | Panasonic | SWITCH TACTILE SPST-NO 0.05A 12V | BT2 | 1 | 0.0220 | 0.0220 | https://www.thegioiic.com/nut-nhan-3x6mm-cao-5mm-2-chan-smd-dau-trang
3 | LC14500 | OEM | BATT LITH-ION 3.7V 1.3AH 14500 | BAT1,BAT2 | 2 | 0.9650 | 1.9300 | https://www.thegioiic.com/pin-sac-14500-1300mah-3-7v
60 | RT9193-33GB | Richtek | IC REG LINEAR 3.3V 300MA SOT23-5 | U10 | 1 | 0.1320 | 0.1320 | https://www.thegioiic.com/rt9193-33gb-ic-on-ap-3-3v-300ma
39 | SI2300DS-T1-GE3 | Vishay | MOSFET N-CH 30V 3.6A SOT23-3 | Q1,Q2 | 2 | 0.0220 | 0.0440 | https://www.thegioiic.com/si2300ds-mosfet-kenh-n-30v-3-6a-sot-23
22 | SMF05CT1G | Onsemi | TVS DIODE 5VWM 12.5V SC88/SC70-6 | D6 | 1 | 0.0310 | 0.0310 | https://www.thegioiic.com/smf05c-esd-protection-diode-array-sot-363
59 | SN74LVC1T45DBVR | TI | IC TRANSLATOR BIDIR SOT23-6 | U8,U9 | 2 | 0.2190 | 0.4380 | https://www.thegioiic.com/sn74lvc1t45dbvr-ic-voltage-level-shifter-bus-transceiver-6-sot-23
18 | SS26 | MDD | DIODE SCHOTTKY 60V 2A SMA | D1,D2,D8 | 3 | 0.0180 | 0.0540 | https://www.thegioiic.com/ss26-sma-diode-schottky-2a
~~27~~ | ~~SOLAR12V-3W-115x115x3~~ | ~~OEM~~ | ~~SOLAR CELL 3W 12V 220MA 115x115x3MM~~ | ~~J2~~ | ~~1~~ | ~~0~~ | ~~0~~ | https://www.thegioiic.com/tam-nang-luong-mat-troi-2w-9v
65 | MC-146 32.7680KA-AC0: ROHS | EPSON | CRYSTAL 32.7680KHZ 9PF SMD | X1 | 1 | 0.1540 | 0.1540 | https://www.thegioiic.com/thach-anh-32-768khz-mc-146-crystal-7015-4-chan
6 | CL10B104KA8NNNC | Samsung | CAP CER 0.1UF 25V X7R 0603 | C1,C6,C12,C16,C17,C25,C27,C34,C41,C42,C46,C47,C51,C61,C66,C70,C74 | 17 | 0.0083 | 0.1411 | https://www.thegioiic.com/tu-gom-0603-100nf-0-1uf-25v
8 | CL10C101JB8NNNC | Samsung | CAP CER 100PF 50V C0G/NP0 0603 | C4,C9,C10,C11,C13,C15,C23,C68,C69 | 9 | 0.0083 | 0.0747 | https://www.thegioiic.com/tu-gom-0603-100pf-50v
13 | CL10C220JB8NFNC | Samsung | CAP CER 22PF 50V C0G/NP0 0603 | C32,C33,C35,C37,C38,C39,C40,C43,C45,C48,C52,C53,C54,C56,C59,C71,C73 | 17 | 0.0083 | 0.1411 | https://www.thegioiic.com/tu-gom-0603-22pf-50v
10 | CL10B225KP8NNNC | Samsung | CAP CER 2.2UF 10V X7R 0603 | C8,C31,C36,C44,C50,C55,C60 | 7 | 0.0180 | 0.1260 | https://www.thegioiic.com/tu-gom-0603-2-2uf-10v
12 | CL10C8R2DB8NNNC | Samsung | CAP CER 8.2PF 50V C0G/NP0 0603 | C28,C29 | 2 | 0.0083 | 0.0166 | https://www.thegioiic.com/tu-gom-0603-8-2pf-50v
7 | CL21A106KOQNNNE | Samsung | CAP CER 10UF 16V X5R 0805 | C2,C3,C7,C14,C18,C21,C22,C24,C30,C62,C63,C64,C67,C75 | 14 | 0.0170 | 0.2380 | https://www.thegioiic.com/tu-gom-0805-10uf-16v
9 | UUD1E471MNL1GS | Nichicon | CAP ALUM 470UF 20% 25V SMD | C5 | 1 | 0.0880 | 0.0880 | https://www.thegioiic.com/tu-nhom-smd-470uf-25v-10x10-5mm
11 | TAJC227K006RNJ | AVX | CAP ALUM 220UF 20% 6.3V SMD 2312 | C19,C20,C26,C49,C65,C72 | 6 | 0.2410 | 1.4460 | https://www.thegioiic.com/tu-tantalum-220uf-6-3v-2312-tajc227k006rnj
 |  |  |  |  |  |  | 28.6843

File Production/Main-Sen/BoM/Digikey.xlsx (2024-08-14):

Index | Digikey Part Number | Manufacturer Part Number | Description | Quantity | Unit Price | Extended Price USD
1 | DPS368XTSA1CT-ND | DPS368XTSA1 | SENSOR 17.4PSIG 24BIT 8VLGA | 2
2 | MCP73871T-2CCI/MLCT-ND | MCP73871T-2CCI/ML | IC BATT CHG LI-ION 1CELL 20QFN | 2
3 | 1649-SHT40I-AD1B-R3CT-ND | SHT40I-AD1B-R3 | INDUSTRIAL SENSOR HUMID/TEMP | 2
4 | 296-53541-1-ND | LM66100DCKR | IC OR CTRLR IDEAL DIODE SC70-6 | 2
5 | 296-47298-1-ND | TPS630701RNMR | IC REG BCK BST 5V 2A 15VQFN | 2
 |  |  |  |  |  | 0.00000

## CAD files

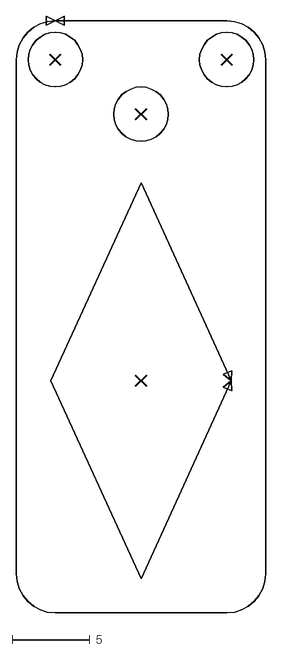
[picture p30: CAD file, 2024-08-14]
Docs/PCBSenSorOutline.dxf
16.0 x 38.3

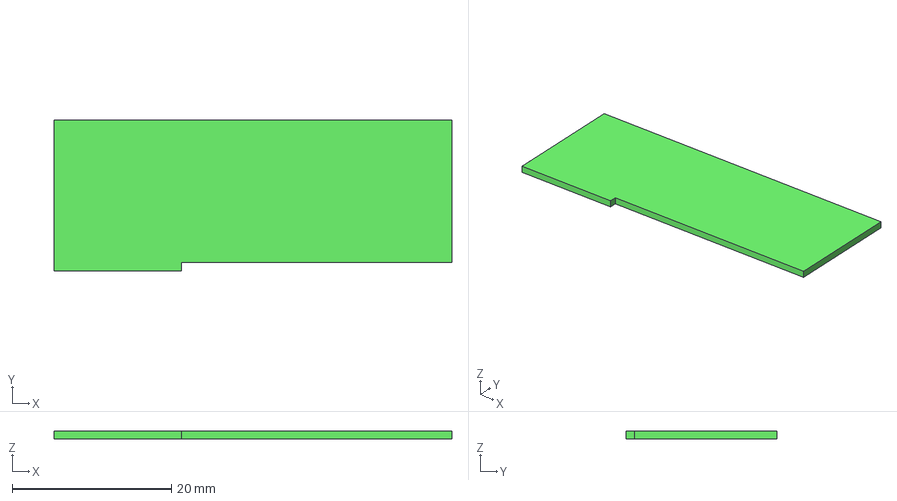
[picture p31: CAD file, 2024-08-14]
Hardware/Model3D/AH3G.step
50.0 x 19.0 x 1.00 mm

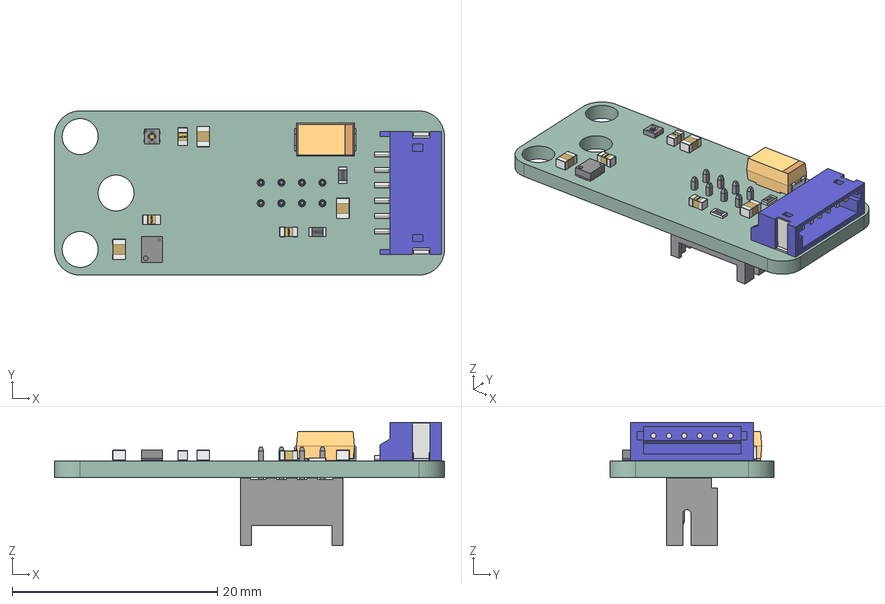
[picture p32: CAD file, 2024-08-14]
Production/DHTP/3D/DHTP.step
38.0 x 16.0 x 12.0 mm
CCS_CCSTD_0603_L1.75W0.95T0.95B0.5 x 3
AF2A9F65-5F86-47DB-BF73-38C91065DB55
User Library-CAPC2013X10 x 3
TAJC686M006RNJ
User Library-R SMD 0603 x 2
S6B-ZR-SM4A
DPS310
DF11-8DP-2DSAÈª
WeatherStation_PCB

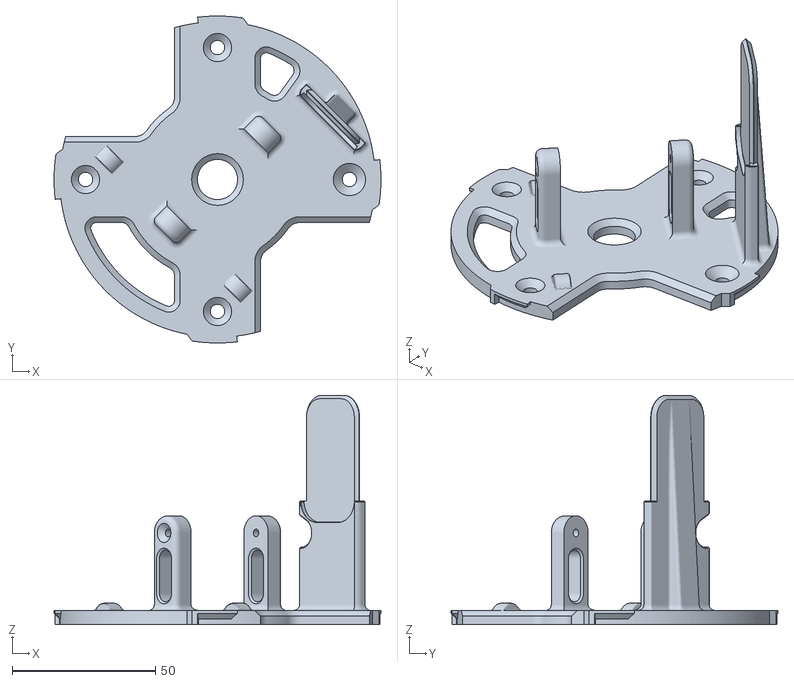
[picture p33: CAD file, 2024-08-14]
Production/Enclosure/Pluvio_-_Base_FIXED.stl
114.0 x 114.0 x 80.0

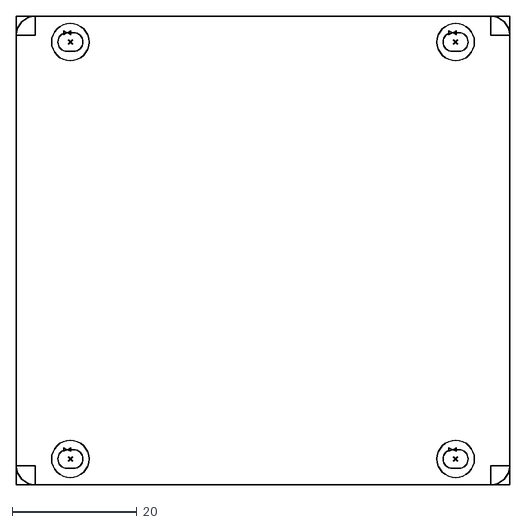
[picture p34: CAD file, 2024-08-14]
Docs/PCBOutline.dxf
79.0 x 75.0

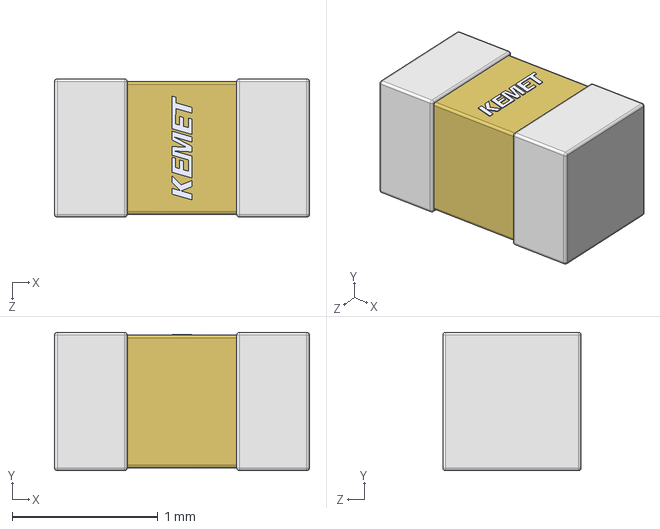
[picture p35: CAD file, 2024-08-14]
Hardware/Model3D/C0603C104K4RACTU.step
1.75 x 0.95 x 0.95 mm

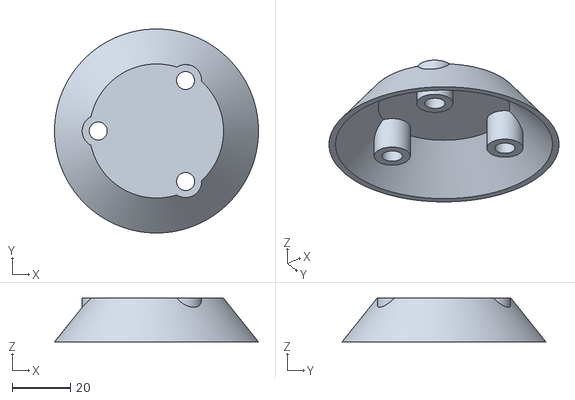
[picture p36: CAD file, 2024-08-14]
Production/Enclosure/Sensor_Hub_Shield_top.stl
70.0 x 70.0 x 15.0

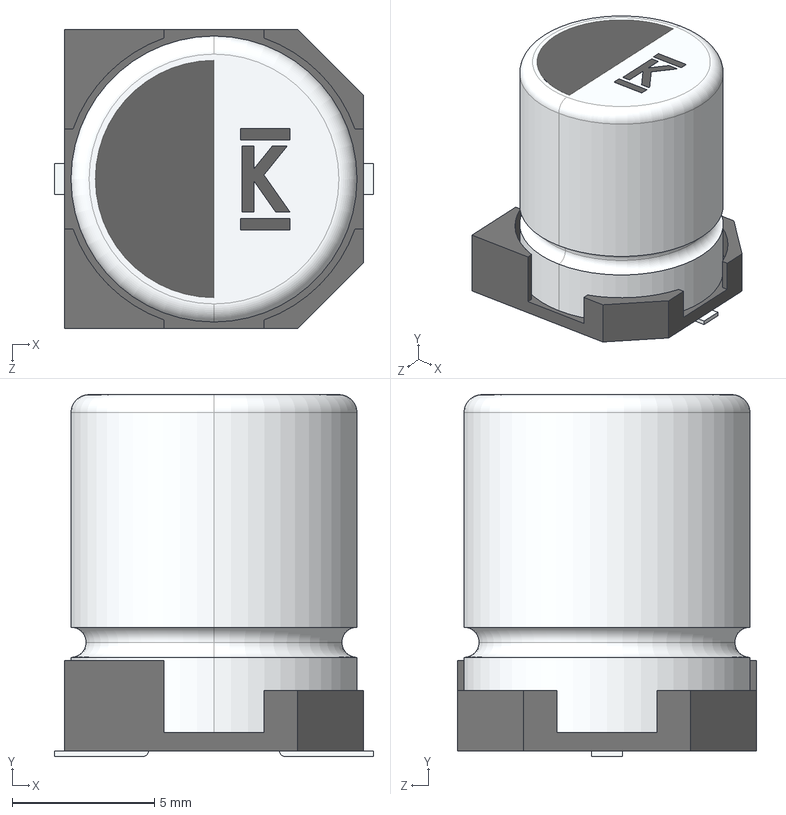
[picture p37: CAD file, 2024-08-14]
Hardware/Model3D/A768MS477M1ELAE017.step
11.2 x 12.7 x 10.5 mm

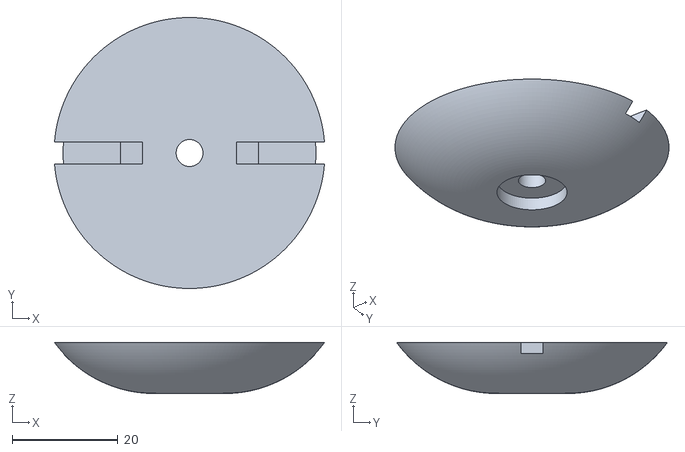
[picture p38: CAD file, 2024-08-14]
Production/Enclosure/Anemo_bottom-High_cap_FIXED.stl
51.0 x 51.2 x 9.64

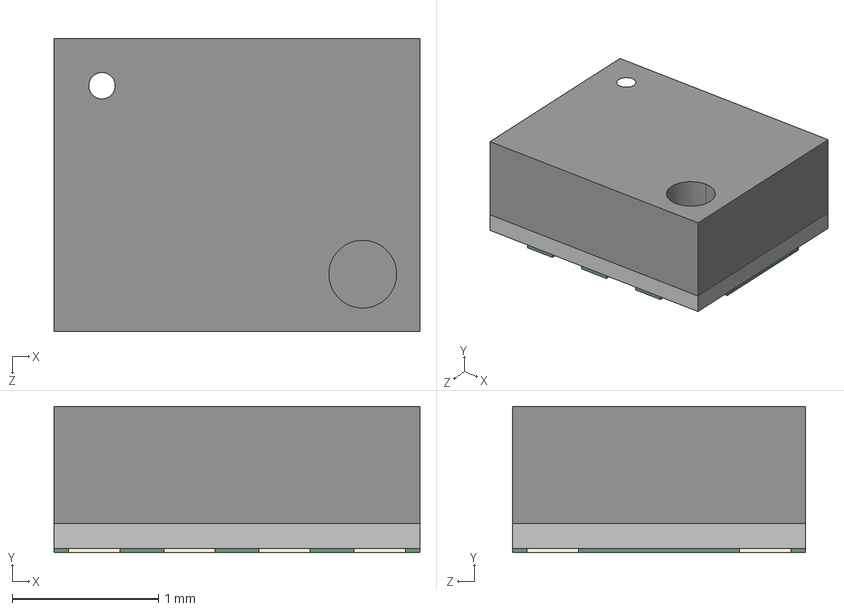
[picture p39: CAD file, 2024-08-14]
Hardware/Model3D/DPS368.step
2.50 x 1.00 x 2.00 mm

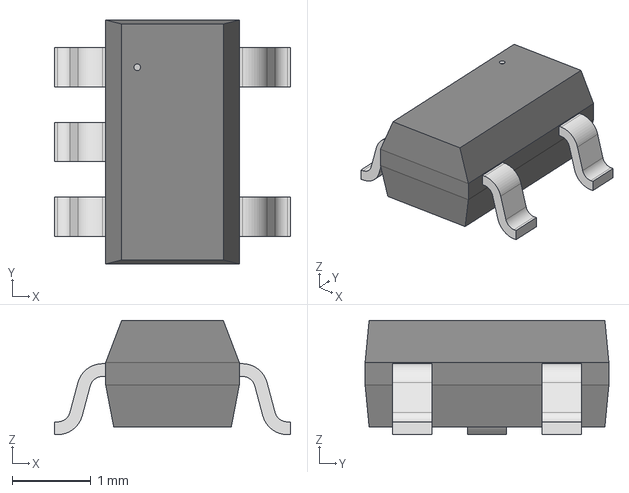
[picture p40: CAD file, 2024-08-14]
Hardware/Model3D/SOT25_DIODES.step
3.00 x 3.10 x 1.45 mm

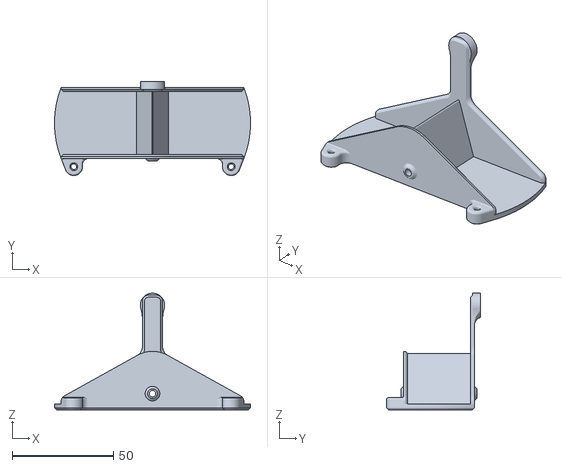
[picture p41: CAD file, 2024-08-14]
Production/Enclosure/Pluvio_-_Tipping_bucket_FIXED.stl
96.6 x 46.3 x 57.5

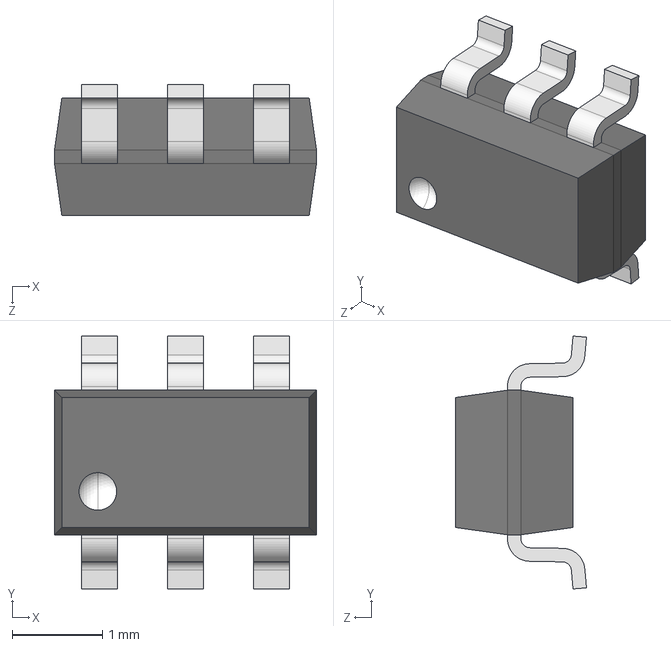
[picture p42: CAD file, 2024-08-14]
Hardware/Model3D/SOT23-6.step
2.90 x 2.80 x 1.45 mm

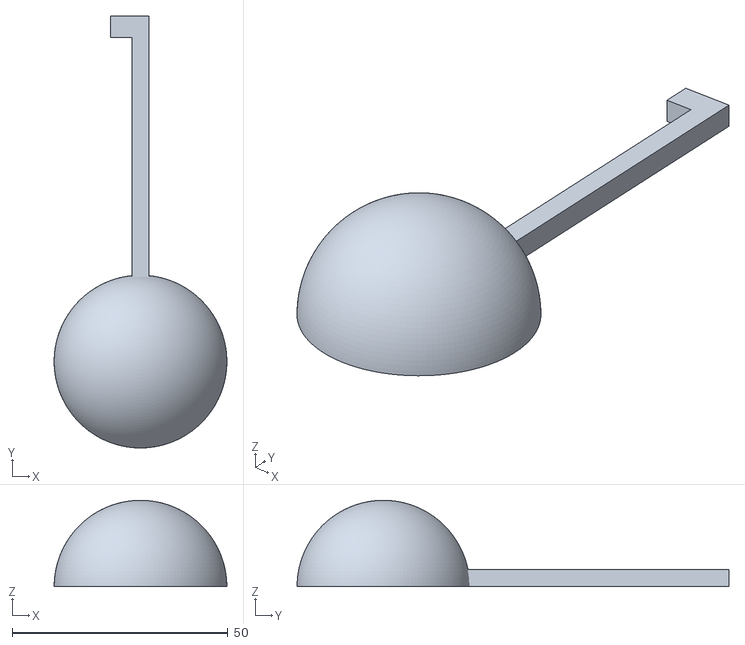
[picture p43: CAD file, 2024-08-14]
Production/Enclosure/Anemo_top_-_Wind_bowl.stl
40.0 x 100.0 x 20.0

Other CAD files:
Hardware/Model3D/XH2.54-4P.step
Production/Enclosure/Sensor_Hub_Shield_2.stl
Hardware/Model3D/SOT23-3.step
Production/Enclosure/Anemo_bottom-Base.stp
Hardware/Model3D/0805C.step
Hardware/Model3D/1575R-A.step
Hardware/Model3D/1812L110_16DR.step
Hardware/Model3D/B052VWVN-RC.step
Hardware/Model3D/CAP2312-6032.step
Hardware/Model3D/CSYTAL-MC146.step
Hardware/Model3D/DO-214AC.step
Hardware/Model3D/EVQ-PE105K_PNF05M_5PN05K.step
Hardware/Model3D/HDM-2x4x2.0-TH.stp
Hardware/Model3D/HDM-6x1.5-SMD-R.step
Hardware/Model3D/IND0603.step
Hardware/Model3D/IND0805.stp
Hardware/Model3D/LED_0603_WS.step
Hardware/Model3D/PH2-04-UA.step
Hardware/Model3D/PowerVQFN15_TI.stp
Hardware/Model3D/QFN20-4x4x0.8MM.step
Hardware/Model3D/RES0603.step
Hardware/Model3D/SHORTINGJUMPER.step
Hardware/Model3D/SHT4x.step
Hardware/Model3D/SIM8051-6-0-14-01-X-REVD.step
Hardware/Model3D/SOIC127P600X175-8N.step
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

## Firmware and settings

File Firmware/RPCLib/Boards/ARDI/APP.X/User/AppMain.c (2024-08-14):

#include "AppMain.h"

typedef enum
{
    APP_INIT=0,
    APP_AT_CHECK,
    APP_RUN,
    APP_ERROR,
    APP_IDLE
} app_task_t;

static struct
{
    tick_timer_t Tick;
    app_task_t Next;
} AppCxt;

uint8_t I2C_Scan(void) // <editor-fold defaultstate="collapsed" desc="Scan I2C slaver">
{
    uint8_t found, slv;

    __dbs("\nScan I2C: ");

    for(slv=1, found=0; slv<128; slv++)
    {
        ClrWdt();

        if(I2C1_Master_Write(slv, NULL, 0))
        {
            found++;
            __dbs("\n-> Found 0x");
            __dbh2(slv);
        }
    }

    return found;
} // </editor-fold>

void Display_Volatge(void) // <editor-fold defaultstate="collapsed" desc="Display all analog inputs as mV">
{
    __tsdbs("VOTAGE (mV):");
    __dbsu("\nVbat=", GetVbat());
    __dbsu("\nVcore=", GetVCore());
    __dbsu("\nVbg=", GetVBGap());
    __dbsu("\nVUno1=", GetUnoAn1());
    __dbsu("\nVUno2=", GetUnoAn2());
    __dbsu("\nVUno3=", GetUnoAn3());
    __dbsu("\nVUnoVref=", GetUnoVref());
} // </editor-fold>

private void APP_DebugCmd_Process(uint8_t *pCmd) // <editor-fold defaultstate="collapsed" desc="Debug CMD process">
{
    str_uppercase(pCmd);

    if(strstr((const char *) pCmd, "AT#CUSTOMAT")!=NULL)
    {

    }
} // </editor-fold>

public void APP_Main_Initialize(void) // <editor-fold defaultstate="collapsed" desc="Application Initialize">
{
    uint8_t deviceCnt;

    __dbs("\n---------- APP INIT ----------\n");
    AppCxt.Next=APP_INIT;
    Tick_Timer_Reset(AppCxt.Tick);
    Indicator_Toggle(0, 500, 500);
    Power_Monitor_Init();
    VCP_Debug_SetRxCallback(APP_DebugCmd_Process);

    if(SST_Init()==1)
        __dbs("\nSST25xx ready");
    else
    {
        AppCxt.Next=APP_ERROR;
        __dbs("\nSST25VF016B error");
    }

    deviceCnt=I2C_Scan();
    __dbsu("\nI2C device found: ", deviceCnt);
    Telit_PwrCtrl_Init();
    Telit_TurnOn(0, 1);
    __dbs("\n------------------------------\n");
} // </editor-fold>

public void APP_Main_Tasks(void) // <editor-fold defaultstate="collapsed" desc="Application Main Task">
{
    int8_t rslt;

    if(Tick_Timer_Is_Over_Ms(AppCxt.Tick, 3000))
    {
        __tsdbs("Press BTN to see voltages");
    }

    switch(MOD_Button_GetState(BUTTON_GetValue()))
    {
        case SINGLE_PRESS:
            Tick_Timer_Reset(AppCxt.Tick);
            Display_Volatge();
            break;

        case HOLD_PRESS:
            break;

        default: // Do nothing
            break;
    }

    switch(AppCxt.Next)
    {
        case APP_INIT:
            if(Telit_Ready())
            {
                __tsdbs("Module running");
                Indicator_Toggle(0, 100, 500);
                ATCMD_Init();
                AppCxt.Next=APP_AT_CHECK;
            }
            else if(!Telit_IsBusy()&&Telit_PwrCtrl_IsError())
            {
                AppCxt.Next=APP_ERROR;
                __tsdbs("Module error: ");

                if(TelitState.dischrErr==1)
                    __dbs("\n->DisChr error");

                if(TelitState.vcelRdy==0)
                    __dbs("\n->Vcell error");

                if(TelitState.vauxRdy==0)
                    __dbs("\n->Vaux error");

                if(TelitState.swRdy==0)
                    __dbs("\n->SW Rdy error");

                if(TelitState.reboot==1)
                    __dbs("\n->Reboot or Sleep");
            }
            break;

        case APP_AT_CHECK:
            rslt=ATCMD_Test(AT_LEAST_1ON, 10);

            if(rslt==RESULT_DONE)
            {
                __tsdbs("Module AT ready");
                Indicator_Toggle(0, 100, 2900);
                AppCxt.Next=APP_IDLE;
            }
            else if(rslt==RESULT_ERR)
            {
                __tsdbs("Module AT error");
                AppCxt.Next=APP_ERROR;
            }
            break;

        case APP_RUN:
            // Do something
            if(Telit_PwrCtrl_IsError())
            {
                __tsdbs("Module error: ");

                if(TelitState.dischrErr==1)
                    __dbs("\n->DisChr error");

                if(TelitState.vcelRdy==0)
                    __dbs("\n->Vcell error");

                if(TelitState.vauxRdy==0)
                    __dbs("\n->Vaux error");

                if(TelitState.swRdy==0)
                    __dbs("\n->SW Rdy error");

                if(TelitState.reboot==1)
                {
                    Indicator_Toggle(0, 500, 500);
                    AppCxt.Next=APP_INIT;
                    __dbs("\n->Reboot or Sleep\nWait module reboot or wakeup");
                }
            }
            break;

        case APP_ERROR:
            if(Telit_IsBusy()==0)
            {
                AppCxt.Next=APP_IDLE;
                Indicator_Toggle(0, 500, 500);
            }
            break;

        case APP_IDLE:
        default:
            break;
    }
} // </editor-fold>

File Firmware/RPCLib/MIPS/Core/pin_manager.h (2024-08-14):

/**
  PIN MANAGER Generated Driver File

  @Company:
    Microchip Technology Inc.

  @File Name:
    pin_manager.h

  @Summary:
    This is the generated manager file for the PIC24 / dsPIC33 / PIC32MM MCUs device.  This manager
    configures the pins direction, initial state, analog setting.
    The peripheral pin select, PPS, configuration is also handled by this manager.

  @Description:
    This source file provides implementations for PIN MANAGER.
    Generation Information :
        Product Revision  :  PIC24 / dsPIC33 / PIC32MM MCUs - 1.170.0
        Device            :  PIC32MM0256GPM048
    The generated drivers are tested against the following:
        Compiler          :  XC32 v2.50
        MPLAB 	          :  MPLAB X v5.45
 */

/*
    (c) 2020 Microchip Technology Inc. and its subsidiaries. You may use this
    software and any derivatives exclusively with Microchip products.

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
    IN NO EVENT WILL MICROCHIP BE LIABLE FOR ANY INDIRECT, SPECIAL, PUNITIVE,
    INCIDENTAL OR CONSEQUENTIAL LOSS, DAMAGE, COST OR EXPENSE OF ANY KIND
    WHATSOEVER RELATED TO THE SOFTWARE, HOWEVER CAUSED, EVEN IF MICROCHIP HAS
    BEEN ADVISED OF THE POSSIBILITY OR THE DAMAGES ARE FORESEEABLE. TO THE
    FULLEST EXTENT ALLOWED BY LAW, MICROCHIP'S TOTAL LIABILITY ON ALL CLAIMS IN
    ANY WAY RELATED TO THIS SOFTWARE WILL NOT EXCEED THE AMOUNT OF FEES, IF ANY,
    THAT YOU HAVE PAID DIRECTLY TO MICROCHIP FOR THIS SOFTWARE.

    MICROCHIP PROVIDES THIS SOFTWARE CONDITIONALLY UPON YOUR ACCEPTANCE OF THESE
    TERMS.
 */

#ifndef _PIN_MANAGER_H
#define _PIN_MANAGER_H
/**
    Section: Includes
 */
#include <xc.h>
#include <stdbool.h>
/**
    Section: Device Pin Macros
 */
/**
  @Summary
    Sets the GPIO pin, RA0, high using LATA0.

  @Description
    Sets the GPIO pin, RA0, high using LATA0.

  @Preconditions
    The RA0 must be set to an output.

  @Returns
    None.

  @Param
    None.

  @Example
    <code>
    // Set RA0 high (1)
    VNB_EN_SetHigh();
    </code>

 */
#define VNB_EN_SetHigh()          ( LATASET = (1 << 0) )
/**
  @Summary
    Sets the GPIO pin, RA0, low using LATA0.

  @Description
    Sets the GPIO pin, RA0, low using LATA0.

  @Preconditions
    The RA0 must be set to an output.

  @Returns
    None.

  @Param
    None.

  @Example
    <code>
    // Set RA0 low (0)
    VNB_EN_SetLow();
    </code>

 */
#define VNB_EN_SetLow()           ( LATACLR = (1 << 0) )

/**
  @Summary
    Sets a value to the GPIO pin.

  @Description
    Sets or Resets the GPIO pin, RA0, low or high using LATA0.

  @Preconditions
    The RA0 must be set to an output.

  @Returns
    None.

  @Param
    bool value; : value to be set to the GPIO pin.

  @Example
    <code>
    // Set RA0 to low.
    VNB_EN_SetValue(false);
    </code>

 */
inline static void VNB_EN_SetValue(bool value) {
    if (value) {
        VNB_EN_SetHigh();
    } else {
        VNB_EN_SetLow();
    }
}

#define PIN_VNB_EN PIN_A0

/**
  @Summary
    Toggles the GPIO pin, RA0, using LATA0.

  @Description
    Toggles the GPIO pin, RA0, using LATA0.

  @Preconditions
    The RA0 must be set to an output.

  @Returns
    None.

  @Param
    None.

  @Example
    <code>
    // Toggle RA0
    VNB_EN_Toggle();
    </code>

 */
#define VNB_EN_Toggle()           ( LATAINV = (1 << 0) )
/**
  @Summary
    Reads the value of the GPIO pin, RA0.

  @Description
    Reads the value of the GPIO pin, RA0.

  @Preconditions
    None.

  @Returns
    None.

  @Param
    None.

  @Example
    <code>
    uint16_t portValue;

    // Read RA0
    postValue = VNB_EN_GetValue();
    </code>

 */
#define VNB_EN_GetValue()         PORTAbits.RA0
/**
  @Summary
    Configures the GPIO pin, RA0, as an input.

  @Description
    Configures the GPIO pin, RA0, as an input.

  @Preconditions
    None.

  @Returns
    None.

  @Param
    None.

  @Example
    <code>
    // Sets the RA0 as an input
    VNB_EN_SetDigitalInput();
    </code>

 */
#define VNB_EN_SetDigitalInput()   ( TRISASET = (1 << 0) )
/**
  @Summary
    Configures the GPIO pin, RA0, as an output.

  @Description
    Configures the GPIO pin, RA0, as an output.

  @Preconditions
    None.

  @Returns
    None.

  @Param
    None.

  @Example
    <code>
    // Sets the RA0 as an output
    VNB_EN_SetDigitalOutput();
    </code>

 */
#define VNB_EN_SetDigitalOutput()   ( TRISACLR = (1 << 0) )
/**
  @Summary
    Sets the GPIO pin, RA1, high using LATA1.

  @Description
    Sets the GPIO pin, RA1, high using LATA1.

  @Preconditions
    The RA1 must be set to an output.

  @Returns
    None.

  @Param
    None.

  @Example
    <code>
    // Set RA1 high (1)
    LED_APP_SetHigh();
    </code>

 */
#define LED_APP_SetHigh()          ( LATASET = (1 << 1) )
/**
  @Summary
    Sets the GPIO pin, RA1, low using LATA1.

  @Description
    Sets the GPIO pin, RA1, low using LATA1.

  @Preconditions
    The RA1 must be set to an output.

  @Returns
    None.

  @Param
    None.
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

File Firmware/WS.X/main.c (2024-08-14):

#include "system.h"
#include "AppMain.h"
#include "Apps/VCP.h"
#include "System/softWdt.h"
#include "System/TickTimer.h"
#include "System/TaskManager.h"
#include "Common/Debug.h"
#include "Indicator/Indicator.h"

static const char HwInfo[]={
    "\n\nWEATHER STATION"
    "\nHARDWARE : HWZ012_REV0.0"
    "\nPCB      : PCB.Y146-3908731A"
    "\nBUILD    : " __TIME__ "-" __DATE__
    "\nCLOCK    : " __make_xstr(_XTAL_FREQ) " Hz"
};

private void ResetCodeDisplay(void) // <editor-fold defaultstate="collapsed" desc="Reset code display">
{
    __dbsh("\n\nRESET CONTROL REGISTER: ", RCON);

    if(RCONbits.PORIO)
        __dbs("\n-->PORIO: A Power-on Reset has occurred due to VDD voltage");

    if(RCONbits.PORCORE)
        __dbs("\n-->PORCORE: A Power-on Reset has occurred due to core voltage");

    if(RCONbits.BCFGERR)
        __dbs("\n-->BCFGERR: An error occurred during a read of the Primary Configuration registers");

    if(RCONbits.BCFGFAIL)
        __dbs("\n-->BCFGFAIL: An error occurred during a read of the Primary and Alternate Configuration registers");

    if(RCONbits.CMR)
        __dbs("\n-->CMR: Configuration Mismatch Reset has occurred");

    if(RCONbits.EXTR)
        __dbs("\n-->EXTR:  Master Clear (pin) Reset has occurred");

    if(RCONbits.SWR)
        __dbs("\n-->SWR: Software Reset was executed");

    if(RCONbits.WDTO)
        __dbs("\n-->WDTO: Watchdog Timer Time-out Flag bit");

    if(RCONbits.SLEEP)
        __dbs("\n-->SLEEP: Device was in Sleep mode");

    if(RCONbits.IDLE)
        __dbs("\n-->IDLE: Device was in Idle mode");

    if(RCONbits.BOR)
        __dbs("\n-->BOR: Brown-out Reset has occurred");

    if(RCONbits.POR)
        __dbs("\n-->POR: Power-on Reset has occurred");

    RCON&=0xFFFFFF20; // Clear bit 7,6,4,3,2,1,0
    __dbs("\n\n");
} // </editor-fold>

private void UdIdDisplay(const uint32_t *pUdId) // <editor-fold defaultstate="collapsed" desc="UDID display">
{
    int i;
    uint8_t *pD=(uint8_t *) pUdId;

    __dbs("\nUDID     : ");

    for(i=0; i<8; i++)
        __dbh2(*pD++);
} // </editor-fold>

int main(void) // <editor-fold defaultstate="collapsed" desc="Main function">
{
    uint32_t udID[2];
    uint8_t DoNext=0;
    tick_timer_t Tick={1, 0, 0};

    SYSTEM_Initialize();
    Tick_Timer_Init();
    TaskManager_Init();
    Indicator_Init();
    softWDT_Init(4, NOT_USE, NULL);
    USB_Device_LoadUDID(udID);
    USBDeviceInit();
    USBDeviceAttach();
    VCP_Init();
    spi2_close();
    I2C1_Close();
    UART1_Deinitialize();
    Indicator_Toggle(0, 250, 250);

    while(1)
    {
        switch(DoNext)
        {
            case 0:
                if(Tick_Timer_Is_Over_Ms(Tick, 10000))
                {
                    DoNext++;
                    __dbs(HwInfo);
                    UdIdDisplay(udID);
                    ResetCodeDisplay();
                    APP_Main_Initialize();
                }
                break;

            default:
                APP_Main_Tasks();
                break;
        }

        TaskManager();
        //SYSTEM_SleepControl();
    }

    return 1;
} // </editor-fold>
